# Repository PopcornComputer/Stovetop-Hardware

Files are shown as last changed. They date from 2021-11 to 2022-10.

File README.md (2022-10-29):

# Stovetop Hardware
[][cc-by-nc-sa]
[][twitter-follow]
[][sourceparts-subreddit]

## Purchase
**Stovetop™** is available for purchase in our webstore: [https://shop.popcorncomputer.com/products/stovetop][webstore]

## Documentation
To view the documentation for **Stovetop™** please visit: [https://docs.popcorncomputer.com/Stovetop][stovetop-docs]

If you have done something cool with **Stovetop™** or feel that something is missing from the documentation, please feel free to open an issue in the [documentation repository][documentation-repo] or submit a Pull Request in that repository. The source files for our documentation website can be found in the /docs folder in the [documentation repository][documentation-repo].

## License & Copyright
This work is licensed under a
[Creative Commons Attribution-NonCommercial-ShareAlike 4.0 International License][cc-by-nc-sa].

[][cc-by-nc-sa]

Source Parts Inc. © 2022

**Stovetop™** is a trademark of Source Parts Inc.

[cc-by-nc-sa]: http://creativecommons.org/licenses/by-nc-sa/4.0/
[cc-by-nc-sa-image]: https://licensebuttons.net/l/by-nc-sa/4.0/88x31.png
[cc-by-nc-sa-shield]: https://img.shields.io/badge/License-CC%20BY--NC--SA%204.0-lightgrey.svg
[twitter-follow]: https://twitter.com/intent/follow?screen_name=sourceparts
[twitter-follow-shield]: https://img.shields.io/twitter/follow/sourceparts?style=social&logo=twitter
[sourceparts-subreddit]: https://reddit.com/r/sourceparts
[reddit-subscribers-shield]: https://img.shields.io/reddit/subreddit-subscribers/sourceparts?style=social
[stovetop-docs]: https://docs.popcorncomputer.com/Stovetop
[webstore]: https://shop.popcorncomputer.com/products/stovetop
[documentation-repo]: https://github.com/PopcornComputer/Stovetop

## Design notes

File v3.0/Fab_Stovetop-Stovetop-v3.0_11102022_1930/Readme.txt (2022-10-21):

Board name	: Stovetop
Rev		: 3.0

Board Technology information:

No. of Layers		- Six(6)

Board Size 		- 72.5mm x 72.5mm

Track/Spacing		- 5mil track and 5mil spacing

Via			- 16mil pad and 8mil drill
               
Component		- Mixed Technology

Gerber Format		- RS274-X

=================================================================

Note :

Please refer fab.gbr for stackup details.

Please confirm IPC netlist verification.

=================================================================

List of files in GERBER / arttoplotting

L1_Top.gbr		-> Gerber, Top side artwork
L2_Gnd.gbr		-> Gerber, Inner layer2 artwork
L3_Sig.gbr		-> Gerber, Inner layer3 artwork
L4_Sig.gbr		-> Gerber, Inner layer4 artwork
L5_Pwr.gbr		-> Gerber, Inner layer5 artwork
L6_Bot.gbr		-> Gerber, Bot side artwork
Soldermask_Top.gbr	-> Gerber, Top side Solder Mask
Soldermask_Bot.gbr	-> Gerber, Bot side Solder Mask
Silk_Top.gbr		-> Gerber, Top side Silkscreen
Silk_Bot		-> Gerber, Bot side Silkscreen
Milling.gml		-> Gml, Milling Details
Profile.gbr		-> Gerber, Outline

List of files in DRILL/ NC Drill

Stovetop_V3.0-1-6.xln		-> NC Drill file in excellon format
Fab.gbr		   		-> Gerber, Fab drawing

Stovetop-v3.0_Release.pdf -> File for visual compliance

Stovetop-v3.0_Release.IPC -> IPC-D-356 netlist

Stovetop-v3.0_Milling.pdf -> Milling Details

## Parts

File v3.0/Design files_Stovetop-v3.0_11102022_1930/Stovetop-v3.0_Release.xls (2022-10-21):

Part | Value | Device | Package
C1 | 10NF/35V | CAP0402-CAP | 0402-CAP
C2 | 10NF/35V | CAP0402-CAP | 0402-CAP
C3 | 10NF/35V | CAP0402-CAP | 0402-CAP
C4 | 10NF/35V | CAP0402-CAP | 0402-CAP
C5 | 10uF | CAP0603-CAP | 0603-CAP
C6 | 100nF | CAPACITOR | 1608_0603
C7 | 22uF | C1206_22UF_50V_10% | C1206
C8 | 10uF | CAP0603-CAP | 0603-CAP
C9 | 22uF | CAP0805 | 805
C10 | 100nF | C0402_100NF_50V_10% | C0402
C11 | 22uF | CAP0805 | 805
C12 | 10uF | CAP0603-CAP | 0603-CAP
C13 | 22uF | CAP0805 | 805
C14 | 22uF | CAP0805 | 805
C15 | 1uF | CAP0603-CAP | 0603-CAP
C16 | 1uF | CAP0603-CAP | 0603-CAP
C17 | 100nF | CAPACITOR | 1608_0603
C18 | 100nF | CAPACITOR | 1608_0603
C19 | 100nF | CAPACITOR | 1608_0603
C20 | 100nF | CAPACITOR | 1608_0603
C21 | 100nF | CAPACITOR | 1608_0603
C22 | 100nF | CAPACITOR | 1608_0603
C23 | 10uF | CAPACITOR | 1608_0603
C24 | 100nF | CAPACITOR | 1608_0603
C25 | 100nF | CAPACITOR | 1608_0603
C26 | 18pF | CAPACITOR | 1608_0603
C27 | 18pF | CAPACITOR | 1608_0603
C28 | 10uF | CAPACITOR | 1608_0603
C29 | 100nF | CAPACITOR | 1608_0603
C30 | 100nF | CAPACITOR | 1608_0603
C31 | 10uF | CAPACITOR | 1608_0603
C32 | 100nF | CAPACITOR | 1608_0603
C33 | 10uF | CAPACITOR | 1608_0603
C34 | 100nF | CAPACITOR | 1608_0603
C35 | 100nF | CAPACITOR | 1608_0603
C36 | 10uF | CAPACITOR | 1608_0603
C37 | 100nF | CAPACITOR | 1608_0603
C38 | 10uF | CAPACITOR | 1608_0603
C39 | 4.7uF | CAPACITOR | 1608_0603
C40 | 4.7uF | CAPACITOR | 1608_0603
C41 | 100nF | CAPACITOR | 1608_0603
C42 | 10uF | CAPACITOR | 1608_0603
C43 | 220pF | CAP0603-CAP | 0603-CAP
C44 | 220pF | CAP0603-CAP | 0603-CAP
C45 | 220pF | CAP0603-CAP | 0603-CAP
C46 | 220pF | CAP0603-CAP | 0603-CAP
C47 | 47uF | CPOL-USD/7343-31W | D/7343-31W
C48 | 47uF | CPOL-USD/7343-31W | D/7343-31W
C49 | 10uF | 4.7UF-0603-6.3V-(10%) | 603
C50 | 0.1uF | CAP0402-CAP | 0402-CAP
C51 | 10uF | 4.7UF-0603-6.3V-(10%) | 603
C52 | 0.1uF | CAP0402-CAP | 0402-CAP
C53 | 0.1uF | CAP0402-CAP | 0402-CAP
C54 | 0.1uF | CAP0402-CAP | 0402-CAP
C55 | 0.01uF | CAP0402-CAP | 0402-CAP
C56 | 10uF | CAP_POL1206 | EIA3216
C57 | 22uF | CAP0805 | 805
C58 | 22uF | CAP0805 | 805
C59 | 1uF | CAP0805 | 805
C60 | 0.1uF | C-USC0402 | C0402
C61 | 10uF | C-USC0402 | C0402
C62 | 47pF | C-USC0402 | C0402
C63 | 47pF | C-USC0402 | C0402
C64 | 1uF | CAP0402-CAP | 0402-CAP
C65 | 1uF | CAP0402-CAP | 0402-CAP
C66 | 0.01uF | CAP0402-CAP | 0402-CAP
C67 | 0.01uF | CAP0402-CAP | 0402-CAP
C68 | 10uF | CAP_POL1206 | EIA3216
C69 | 0.1uF | CAP0402-CAP | 0402-CAP
C70 | 100nF | C-EUC0402 | C0402
C71 | 22nF | CAP0805 | 805
C72 | 22uF | CAP0805 | 805
C73 | 1uF | CAP0805 | 805
C74 | 0.1uF/50V | CAP0603-CAP | 0603-CAP
C75 | 10uF | CAP0603-CAP | 0603-CAP
C76 | 10uF | CAP0603-CAP | 0603-CAP
C77 | 0.1uF/50V | CAP0603-CAP | 0603-CAP
C78 | 22uF | CAP0805 | 805
C79 | 22uF | CAP0805 | 805
C80 | 22uF | CAP0805 | 805
C81 | 100nF | C-EUC0402 | C0402
C82 | 100nF | C-EUC0402 | C0402
C83 | 0.1uF | C-EUC0603 | C0603
C84 | 0.1uF | C-EUC0603 | C0603
C85 | 0.1uF | C-EUC0603 | C0603
C86 | 0.01uF | C-EUC0603 | C0603
C87 | 0.01uF | C-EUC0603 | C0603
C88 | 10uF | CPOL-EUSMCA | SMC_A
C89 | 27pf | C-EUC0603 | C0603
C90 | 27pf | C-EUC0603 | C0603
C91 | 0.1uF | C-EUC0603 | C0603
C92 | 6.8nF | C-EUC0603 | C0603
C93 | 6.8nF | C-EUC0603 | C0603
D1 | D-SEMTECH-RCLAMP0504S | D-SEMTECH-RCLAMP0504S | T_SOT95P285X90-6N
D2 | D-SEMTECH-RCLAMP0504S | D-SEMTECH-RCLAMP0504S | T_SOT95P285X90-6N
D3 | D-SEMTECH-RCLAMP0504S | D-SEMTECH-RCLAMP0504S | T_SOT95P285X90-6N
D4 | B240A | B240A | SMA
J1 | POCKETCHIP-V1.0_98401-801-40LF | POCKETCHIP-V1.0_98401-801-40LF | POCKETCHIP-V1.0_98401-801-40LF
J2 | HR911105A | HR911105A | HR911105A
J3 | STOVETOP-V2.0_03062020_1600_STOVETOP-V2.0_CHECK_TRISTAN-ROBITAILLE'S-LIBRARY_DX07S024JJ2_USB_TYPE-C | STOVETOP-V2.0_03062020_1600_STOVETOP-V2.0_CHECK_TRISTAN-ROBITAILLE'S-LIBRARY_DX07S024JJ2_USB_TYPE-C | STOVETOP-V2.0_03062020_1600_STOVETOP-V2.0_CHECK_TRISTAN-ROBITAILLE'S-LIBRARY_DX07S0224JJ2_USB-C
J4 | STOVETOP-V2.0_03062020_1600_STOVETOP-V2.0_CHECK_TRISTAN-ROBITAILLE'S-LIBRARY_DX07S024JJ2_USB_TYPE-C | STOVETOP-V2.0_03062020_1600_STOVETOP-V2.0_CHECK_TRISTAN-ROBITAILLE'S-LIBRARY_DX07S024JJ2_USB_TYPE-C | STOVETOP-V2.0_03062020_1600_STOVETOP-V2.0_CHECK_TRISTAN-ROBITAILLE'S-LIBRARY_DX07S0224JJ2_USB-C
J5 |  | CONN_02LOCK | 1X02_LOCK
J6 |  | CONN_02LOCK | 1X02_LOCK
J8 | HDMI_T_MOLEX_45171 | CHIP_HDMI_T_MOLEX_45171 | CHIP_HDMI_T_MOLEX_45171
JP1 | JUMPER-SMT_3_1-NC_PASTE_SILK | JUMPER-SMT_3_1-NC_PASTE_SILK | SMT-JUMPER_3_1-NC_PASTE_SILK
JP2 | JUMPER-SMT_3_1-NC_PASTE_SILK | JUMPER-SMT_3_1-NC_PASTE_SILK | SMT-JUMPER_3_1-NC_PASTE_SILK
JP4 | JUMPER-PAD-2-NC_BY_TRACE | JUMPER-PAD-2-NC_BY_TRACE | PAD-JUMPER-2-NC_BY_TRACE_YES_SILK
JP5 | JUMPER-PAD-2-NC_BY_TRACE | JUMPER-PAD-2-NC_BY_TRACE | PAD-JUMPER-2-NC_BY_TRACE_YES_SILK
L1 | IND_4.7UH | IND_4.7UH | IND_4.7UH
L2 | ACML | ACML | 603
L3 | ACML | ACML | 603
L4 | ACML | ACML | 603
L5 | ACML | ACML | 603
L6 | ACML | ACML | 603
L7 |  | WE-KIL_0805 | WE-KI_0805_B
Q5 | FTX25.000M12SM3S | CRISTALLI_0846_FTX25.000M12SM3S | CRISTALLI_CRYSTAL3.2X2.5
R1 | 49R9 1% | R-EU_R0603 | R0603
R2 | 49R9 1% | R-EU_R0603 | R0603
R3 | 49R9 1% | R-EU_R0603 | R0603
R4 | 19.1K | R-US_R0402 | R0402
R5 | 10K | R-US_R0402 | R0402
R6 | 49R9 1% | R-EU_R0603 | R0603
R7 | 28K | R-US_R0402 | R0402
R8 | 1.2K | RESISTOR | J1-0603
R9 | 6.7K | RESISTOR | J1-0603
R10 | 10K | R-US_R0402 | R0402
R11 | 10K | R-US_R0402 | R0402
R12 | 4.7K | R0402_4K7_5% | R0402
R13 | 10K | R-US_R0402 | R0402
R14 | 6.7K | RESISTOR | J1-0603
R15 | 1M | RESISTOR | J1-0603
R16 | 10k | RESISTOR | J1-0603
R17 | 10k | RESISTOR | J1-0603
R18 | 10k | RESISTOR | J1-0603
R19 | 10k | RESISTOR | J1-0603
R20 | 10k | RESISTOR | J1-0603
R21 | 10k | RESISTOR | J1-0603
R22 | 47k | RESISTOR | J1-0603
R23 | 1M | R-US_R0402 | R0402
R24 | 10K | R-US_R0402 | R0402
R25 | 330K | R-US_R0402 | R0402
R26 | 20K | R-US_R0603 | R0603
R27 | 1K1 | R-EU_R0603 | R0603
R28 | 100K | R-US_R0402 | R0402
R29 | 100K | R-US_R0402 | R0402
R30 | 10K | R-US_R0402 | R0402
R31 | 10K | R-US_R0402 | R0402
R32 | 10K | R-US_R0402 | R0402
R33 | 10K | R-US_R0402 | R0402
R34 | 10K | R-US_R0402 | R0402
R35 | 1K1 | R-EU_R0603 | R0603
R36 | 100K | RESISTOR | J1-0603
R37 | 12.4K 1% | R-EU_R0603 | R0603
R38 | 100K | RESISTOR | J1-0603
R39 | 1K | R-US_R0402 | R0402
R40 | 1K | R-US_R0402 | R0402
R41 | 10R, 1/12W, 1% | R-EU_R0603 | R0603
R42 | 100K | R-EU_R0603 | R0603
R44 | 22R | R-EU_R0603 | R0603
R45 | 0 | R-US_R0402 | R0402
R46 | 27R | R-US_R0402 | R0402
R47 | 27R | R-US_R0402 | R0402
R48 | 100K | RESISTOR | J1-0603
R49 | 100K | RESISTOR | J1-0603
R50 | 100R | RESISTOR | J1-0603
R51 | 100R | RESISTOR | J1-0603
R52 | 100K | RESISTOR | J1-0603
RX_LED | Blue | LED805 | LED-805
S1 | 1TS009A | 1TS009A | 1TS009A
S2 | 1TS009A | 1TS009A | 1TS009A
SJ3 | SPARKFUN_SOLDERJUMPERTRACE | SPARKFUN_SOLDERJUMPERTRACE | SPARKFUN_SJ_2S-TRACE
TP1 | CHIP_HDMI_TEST_POINT | CHIP_HDMI_TEST_POINT | CHIP_HDMI_TP-1MMX1MM
TP2 | TEST_POINT | TEST_POINT | TP-1MMX1MM
TP4 | TEST_POINT | TEST_POINT | TP-1MMX1MM
TP5 | TEST_POINT | TEST_POINT | TP-1MMX1MM
TP6 | TEST_POINT | TEST_POINT | TP-1MMX1MM
TP7 | TEST_POINT | TEST_POINT | TP-1MMX1MM
TP8 | TEST_POINT | TEST_POINT | TP-1MMX1MM
TP9 | TEST_POINT | TEST_POINT | TP-1MMX1MM
TP10 | TEST_POINT | TEST_POINT | TP-1MMX1MM
TP11 | TEST_POINT | TEST_POINT | TP-1MMX1MM
TP12 | TEST_POINT | TEST_POINT | TP-1MMX1MM
TP13 | TEST_POINT | TEST_POINT | TP-1MMX1MM
TVS1 | TVS2200 | TVS2200 | TVS2200
TVS2 | TVS2200 | TVS2200 | TVS2200
TX_LED | Amber | LED805 | LED-805
U1 | TPD6S300 | TPD6S300 | TPD6S300
U2 | TPD6S300 | TPD6S300 | TPD6S300
U3 | DS2431P | DS2431P | TSOC6
U4 | CH7053A | CH7053A | QFN40P1000X1000X90_HS-89M
U5 | LP5907MFX | LP5907MFX | SOT23-5
U6 | MP28167GQ | MP28167GQ | MP28167GQ
U7 | PCM1803SMD | PCM1803SMD | SSOP20
U8 | TPS65988 | TPS65988 | TPS65988
U9 | W25X05CLSNIG | W25X05CLSNIG | W25X05CLSNIG
U10 | ENC424J600 | ENC424J600 | TQFP44
UN0 | FT230XS | FT230XS | SSOP-16
Y1 | ABM3B | ABM3B | ABM3B
Y2 | 24.576MHz OSCILLATOR | OSCILLATORSMD6 | CRYSTAL-SMD-7.5X5.2-6PIN

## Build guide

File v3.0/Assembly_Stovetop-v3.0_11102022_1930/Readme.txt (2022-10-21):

Board name	: Stovetop
Rev		: 3.0

Board Technology information:

No. of Layers		- Six(6)

Board Size 		- 72.5mm x 72.5mm

Track/Spacing		- 5mil track and 5mil spacing

Via			- 16mil pad and 8mil drill
               
Component		- Mixed Technology

Gerber Format		- RS274-X

=================================================================

List of files in ASSY/ for Assembly

Paste_Top.gbr		  -> Gerber, Top Side Solder Paste
Paste_Bot.gbr		  -> Gerber, Bot Side Solder Paste
Stovetop-v3.0_Release-smd -> smd component xy location
Stovetop-v3.0_Release-tht -> tht component xy location

Stovetop-v3.0_Assembly.pdf -> File for visual compliance

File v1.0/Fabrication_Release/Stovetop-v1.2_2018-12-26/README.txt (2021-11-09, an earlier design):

Board name	: Stovetop-v1	
Rev		: v0.9

Board Technology information:

No. of Layers		- FOUR(4)

Board Size 		 - 72.5mm x 64mm
               
Component		- Mixed Technology

Gerber Format		- RS274-X

Soldermask Color: WHITE
Silkscreen Color: BLACK

PCB Thickness: 1.6mm
PCB Finish: ENIG
Copper Thickness: 1oz

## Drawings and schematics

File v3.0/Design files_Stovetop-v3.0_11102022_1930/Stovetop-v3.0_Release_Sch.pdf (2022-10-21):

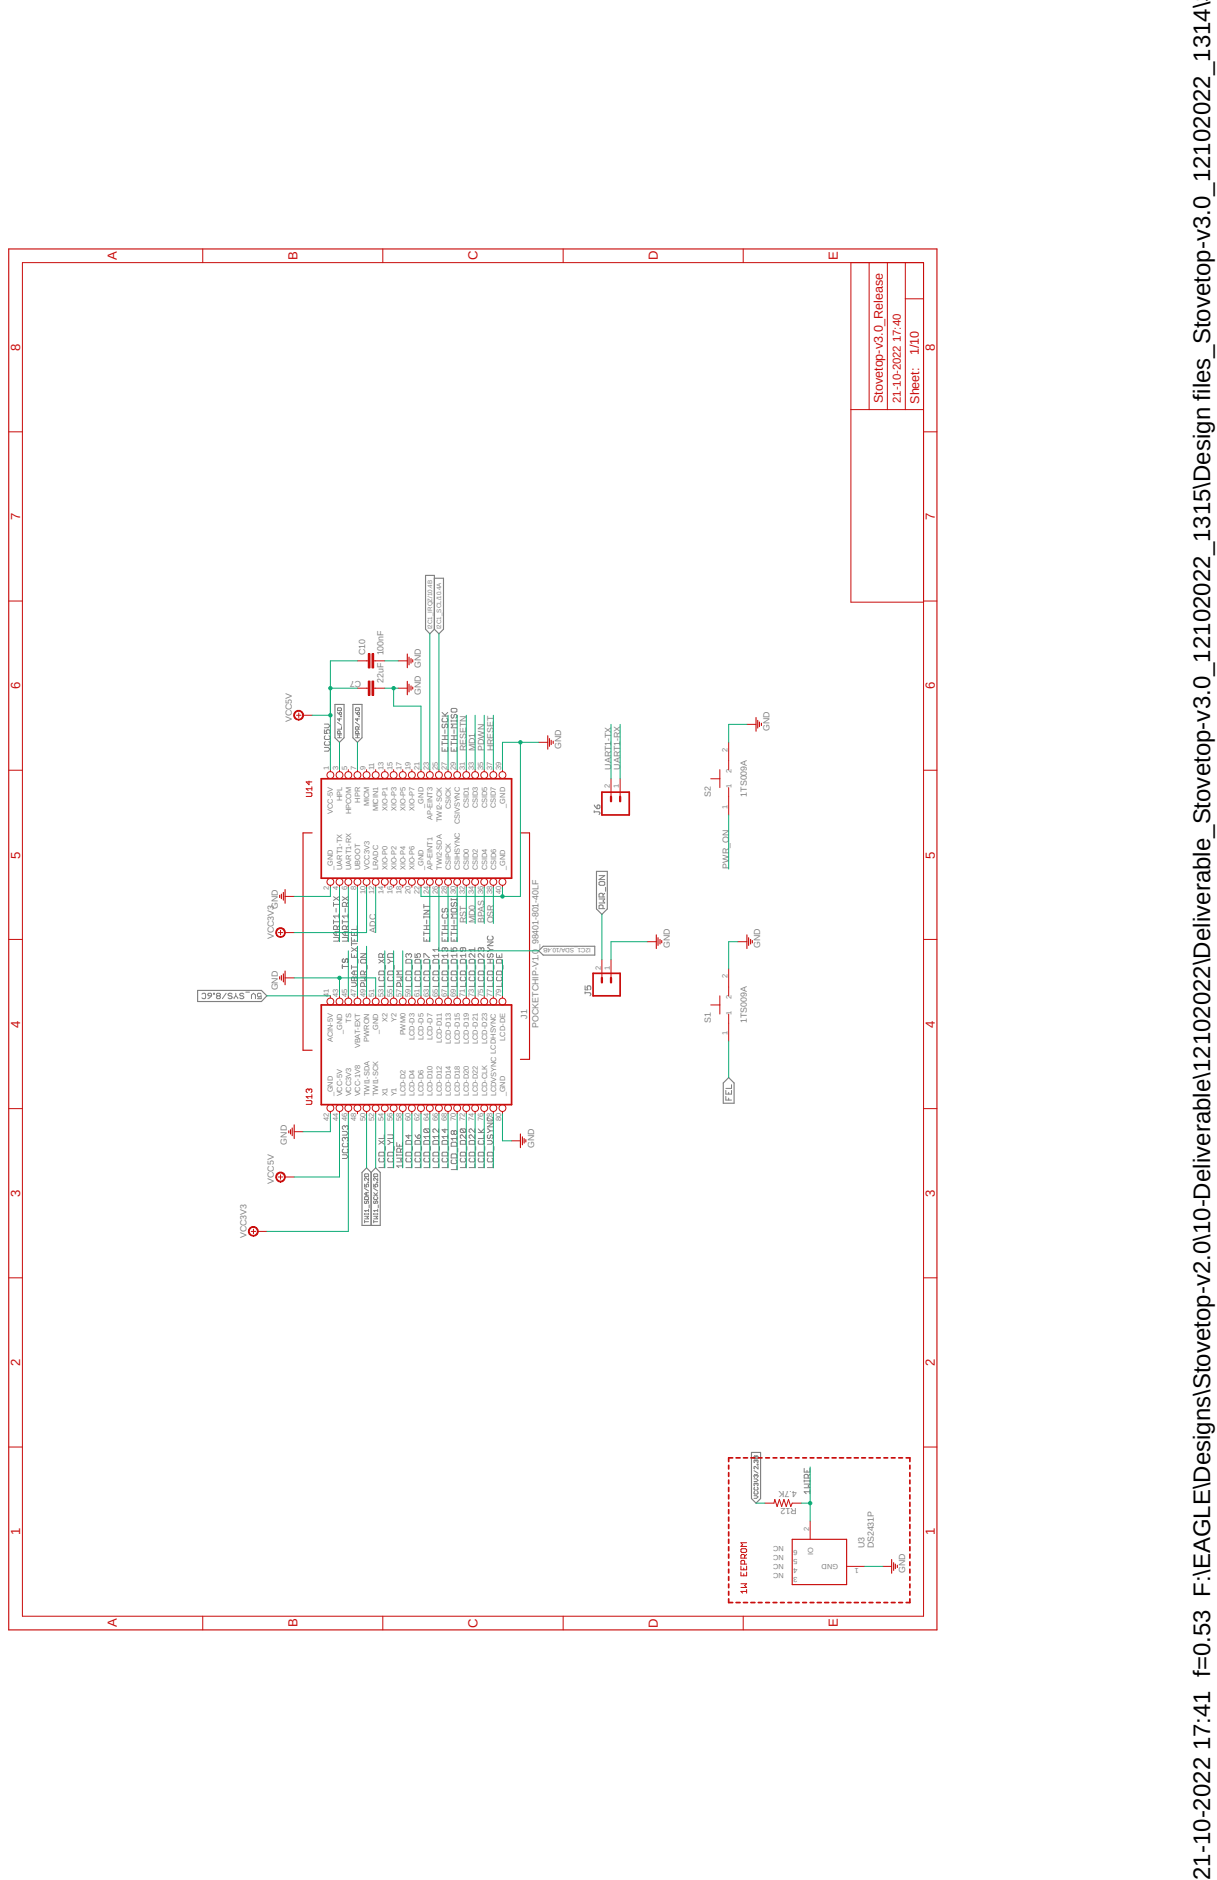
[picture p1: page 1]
GND; GND GND; VCC5V; VCC3V3; POCKETCHIP-V1.0_98401-801-40LF; ACIN-5V 41; AP-EINT1 24 AP-EINT3 23; CSICK 27; CSID0 32 CSID1 31 CSID2 34 CSID3 33 CSID4 36 CSID5 35 CSID6 38 CSID7 37; HPCOM 5; HPL 3; HPR 7; LCD-CLK 76; LCD-D2 58; LCD-D3 59 LCD-D4 60; LCD-D5 61 LCD-D6 62; LCD-D7 63 LCD-D10 64; LCD-D11 65 LCD-D12 66 LCD-D13 67 LCD-D14 68; LCD-D15 69 LCD-D18 70; LCD-D19 71 LCD-D20 72; LCD-D21 73 LCD-D22 74; LCD-D23 75; LRADC 12 MICIN1 11 MICM 9; PWM0 57; PWRON 49; TWI1-SCK 52 TWI1-SDA 50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

21-10-2022 17:41 f=0.53 F:\EAGLE\Designs\Stovetop-v2.0\10-Deliverable\12102022\Deliverable_Stovetop-v3.0_12102022_1315\Design files_Stovetop-v3.0_12102022_1314\Stovetop-v3.0_Release.sch (Sheet: 1/10)

CSIHSYNC 30 CSIPCK 28 CSIVSYNC 29

UBOOT 8 VBAT-EXT 47 VCC-1V8 48

LCD-DE 79 LCDHSYNC 77 LCDVSYNC 78

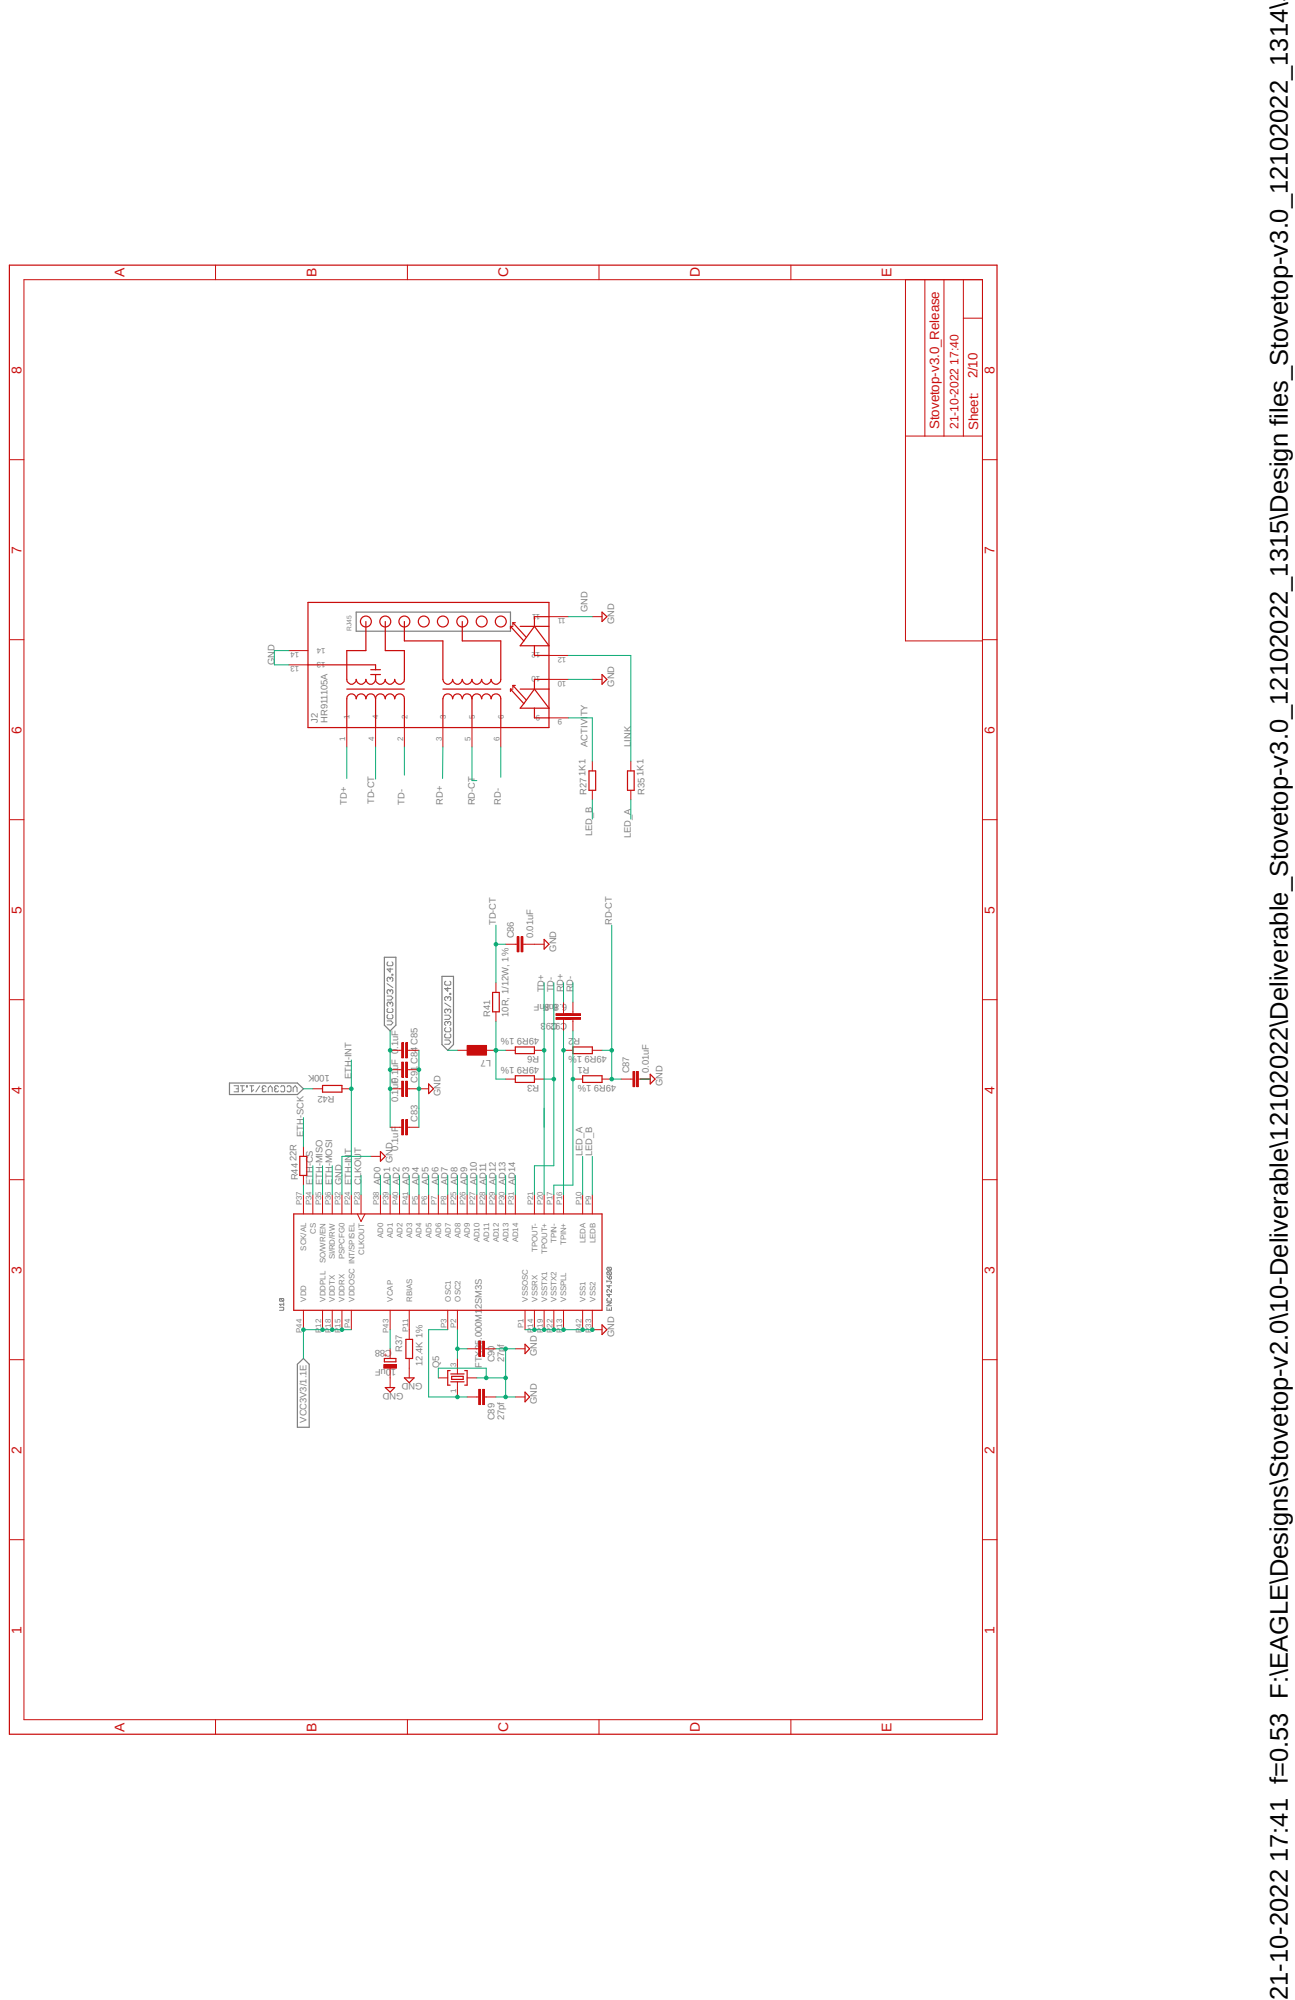
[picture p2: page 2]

21-10-2022 17:41 f=0.53 F:\EAGLE\Designs\Stovetop-v2.0\10-Deliverable\12102022\Deliverable_Stovetop-v3.0_12102022_1315\Design files_Stovetop-v3.0_12102022_1314\Stovetop-v3.0_Release.sch (Sheet: 2/10)

ETH-INT

21-10-2022 17:41 f=0.53 F:\EAGLE\Designs\Stovetop-v2.0\10-Deliverable\12102022\Deliverable_Stovetop-v3.0_12102022_1315\Design files_Stovetop-v3.0_12102022_1314\Stovetop-v3.0_Release.sch (Sheet: 3/10)

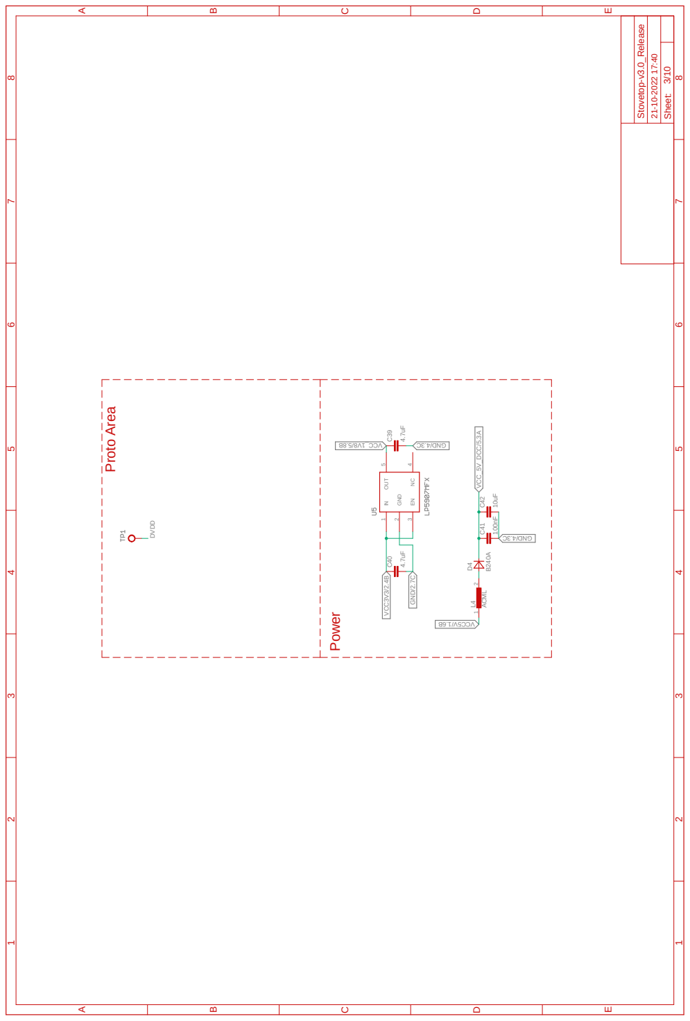
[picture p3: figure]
ACML; GND 2; OUT 5; GND/2.7C; VCC_5V_DCC/5.3A; DVDD; VCC3V3/2.4B; Proto Area; Power; Sheet:; Stovetop-v3.0_Release
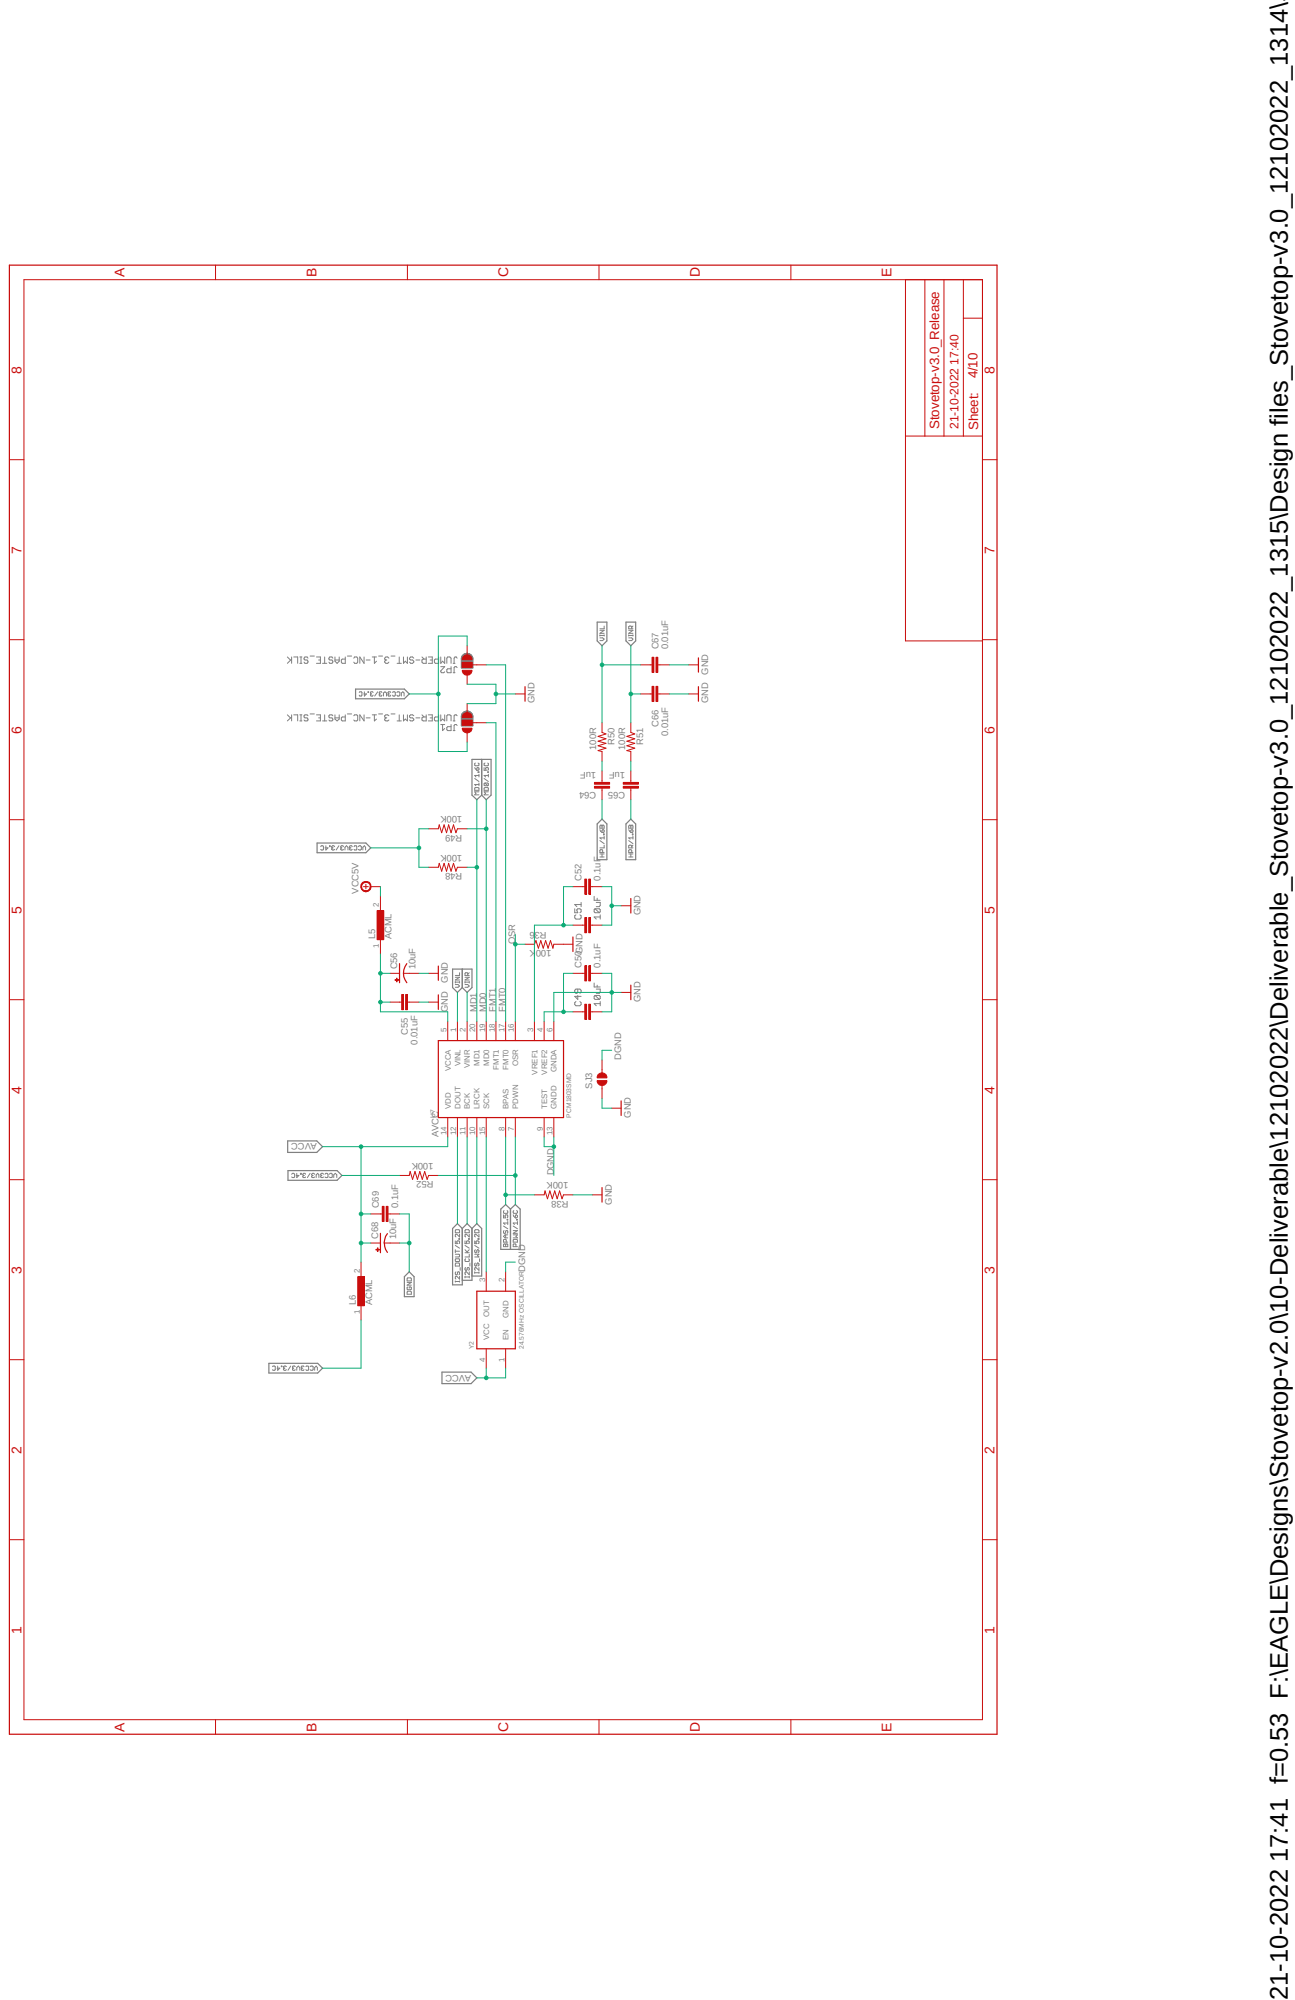
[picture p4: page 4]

21-10-2022 17:41 f=0.53 F:\EAGLE\Designs\Stovetop-v2.0\10-Deliverable\12102022\Deliverable_Stovetop-v3.0_12102022_1315\Design files_Stovetop-v3.0_12102022_1314\Stovetop-v3.0_Release.sch (Sheet: 4/10)

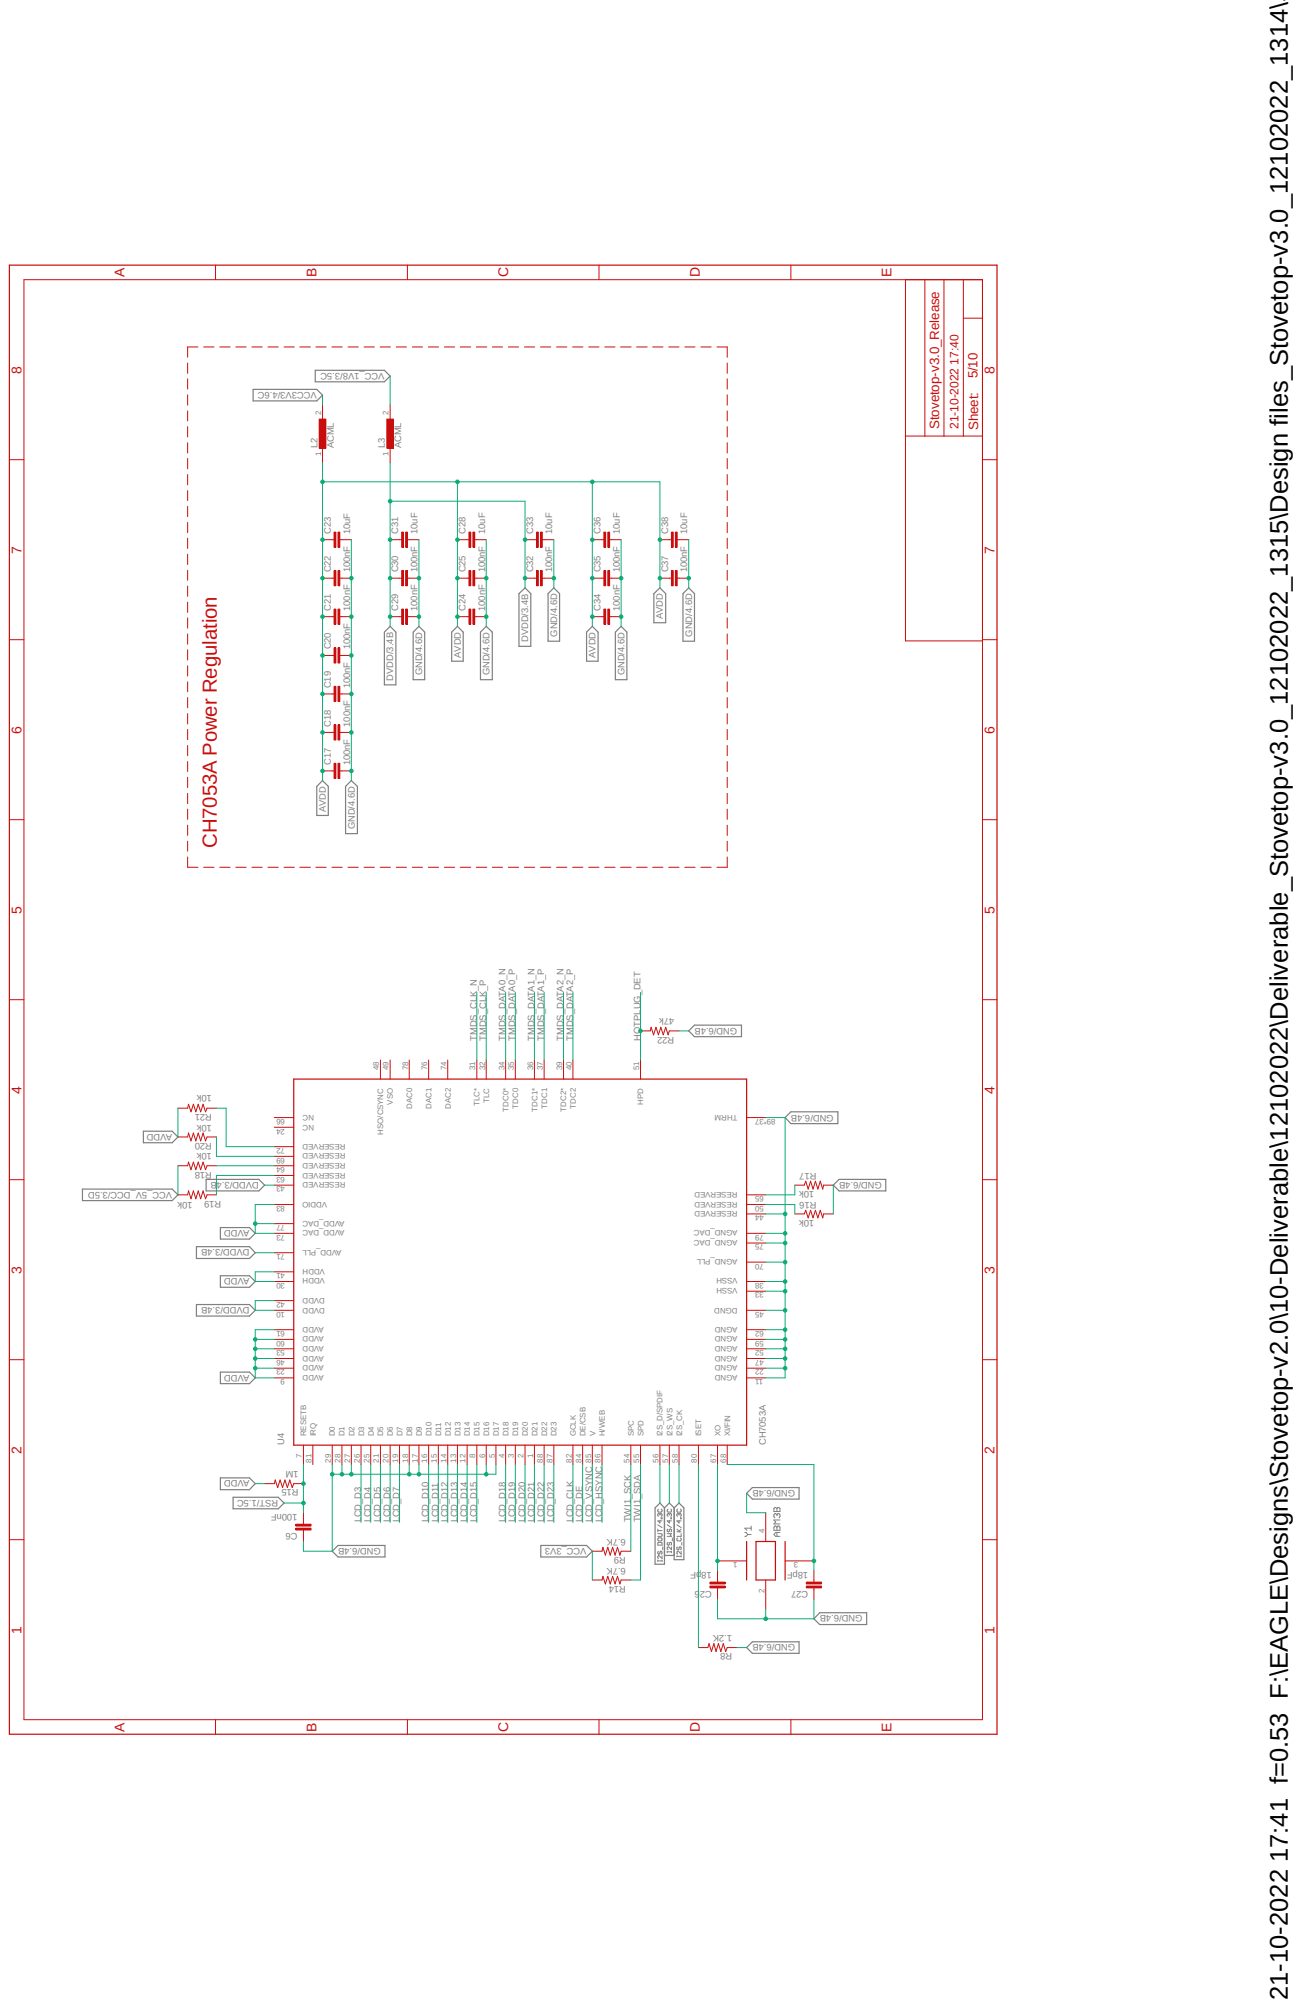
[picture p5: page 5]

21-10-2022 17:41 f=0.53 F:\EAGLE\Designs\Stovetop-v2.0\10-Deliverable\12102022\Deliverable_Stovetop-v3.0_12102022_1315\Design files_Stovetop-v3.0_12102022_1314\Stovetop-v3.0_Release.sch (Sheet: 5/10)

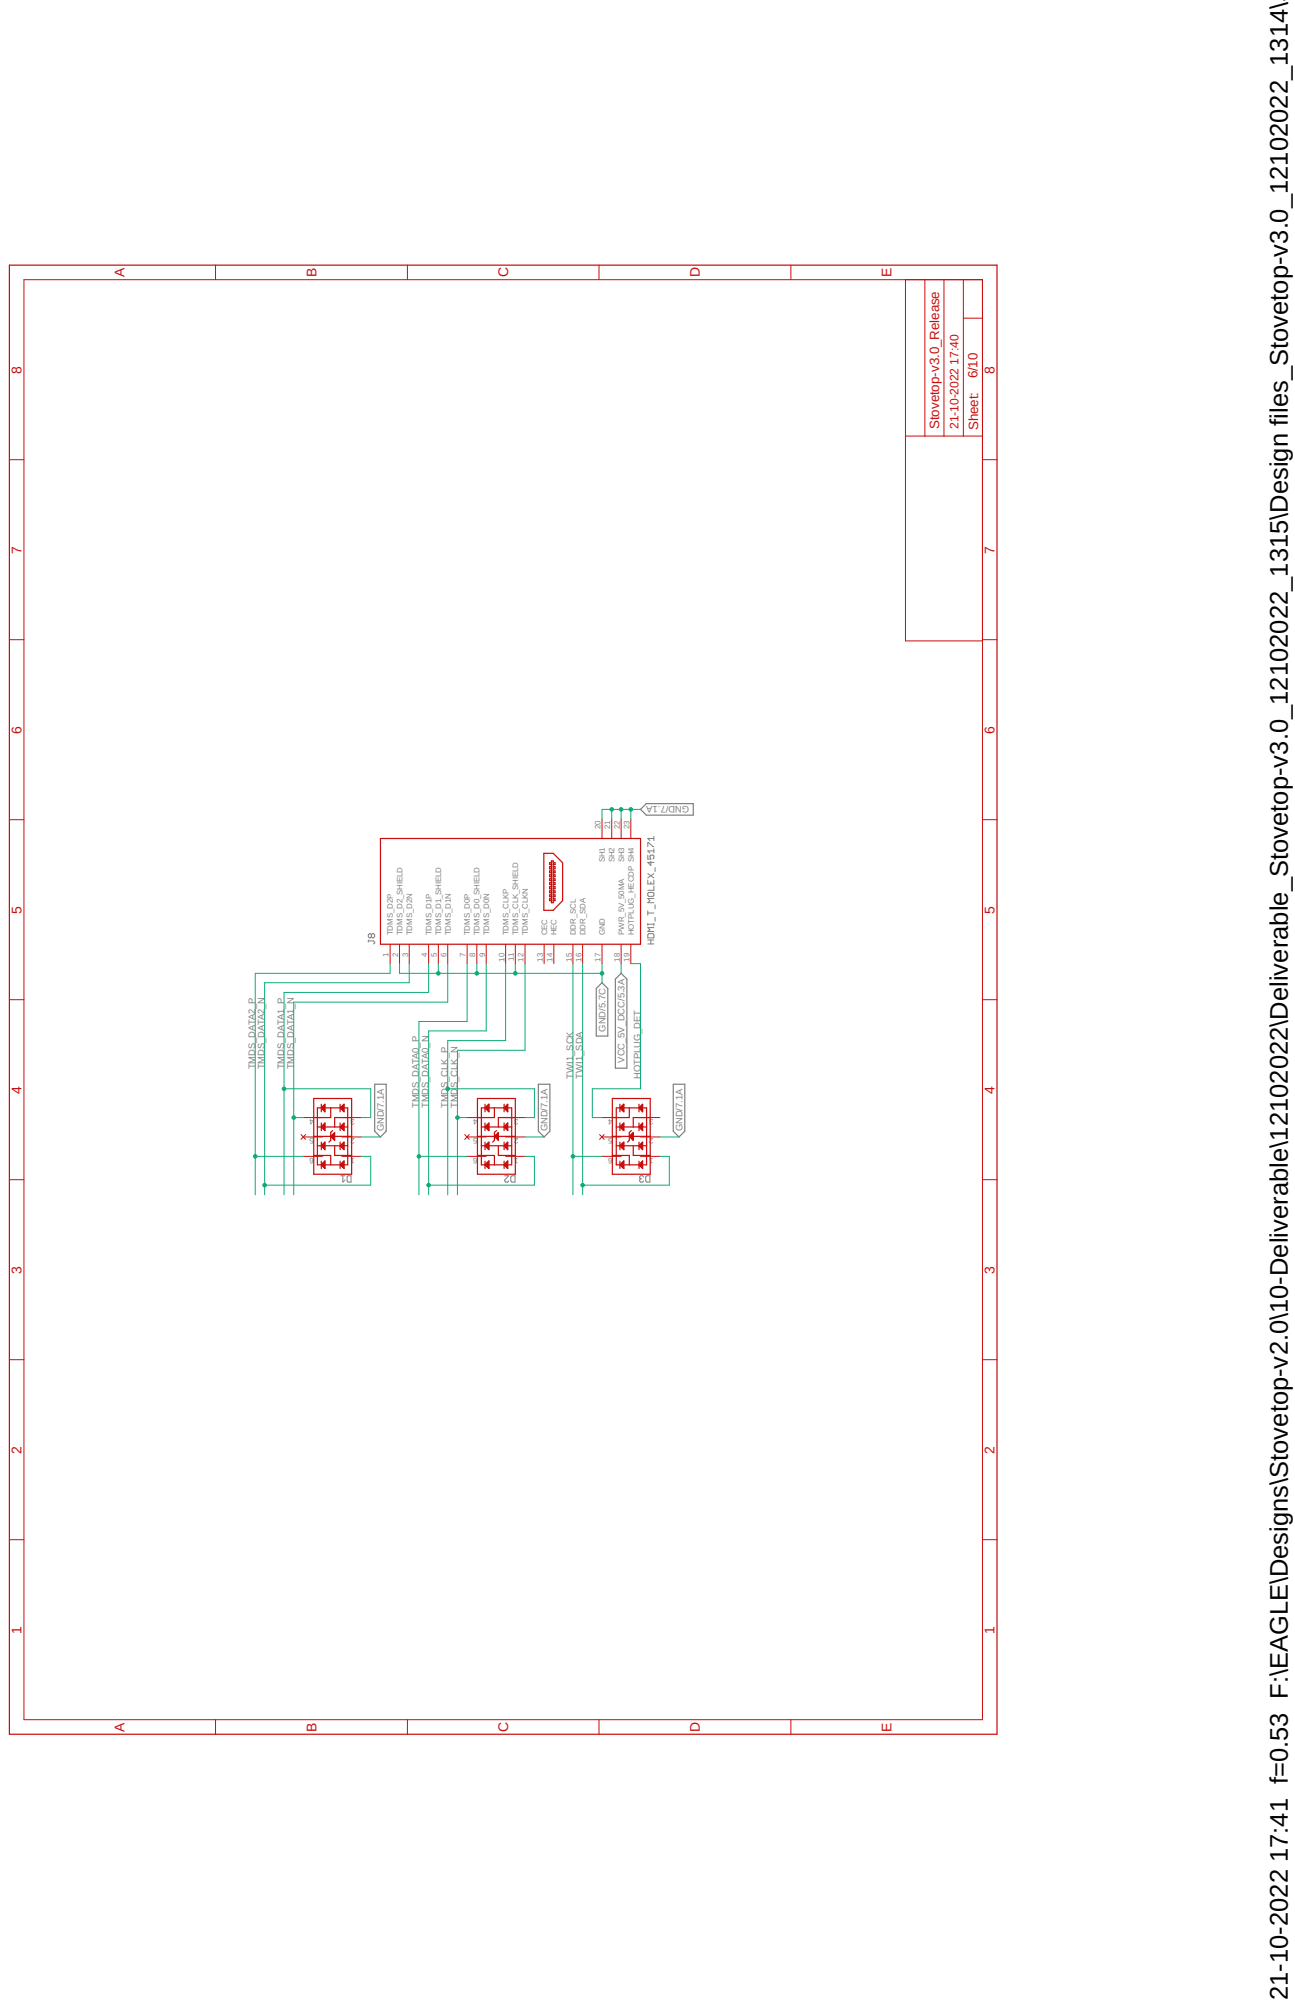
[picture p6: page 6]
CEC 13; DDR_SCL 15; DDR_SDA 16; GND 17; HEC 14; HOTPLUG_HECDP 19 PWR_5V_50MA 18; TDMS_CLKN 12; TDMS_CLKP 10; TDMS_CLK_SHIELD 11; TDMS_D0N 9; TDMS_D0P 7; TDMS_D0_SHIELD 8; TDMS_D1N 6; TDMS_D1P 4; TDMS_D1_SHIELD 5; TDMS_D2N 3; TDMS_D2P 1; TDMS_D2_SHIELD 2; GND/7.1A; GND/5.7C; TMDS_DATA2_P; TMDS_DATA2_N; TMDS_DATA1_P; TMDS_DATA1_N; TMDS_DATA0_P; TMDS_DATA0_N; TMDS_CLK_P; TMDS_CLK_N; TWI1_SCK; TWI1_SDA; HOTPLUG_DET; VCC_5V_DCC/5.3A; Sheet:; Stovetop-v3.0_Release

21-10-2022 17:41 f=0.53 F:\EAGLE\Designs\Stovetop-v2.0\10-Deliverable\12102022\Deliverable_Stovetop-v3.0_12102022_1315\Design files_Stovetop-v3.0_12102022_1314\Stovetop-v3.0_Release.sch (Sheet: 6/10)

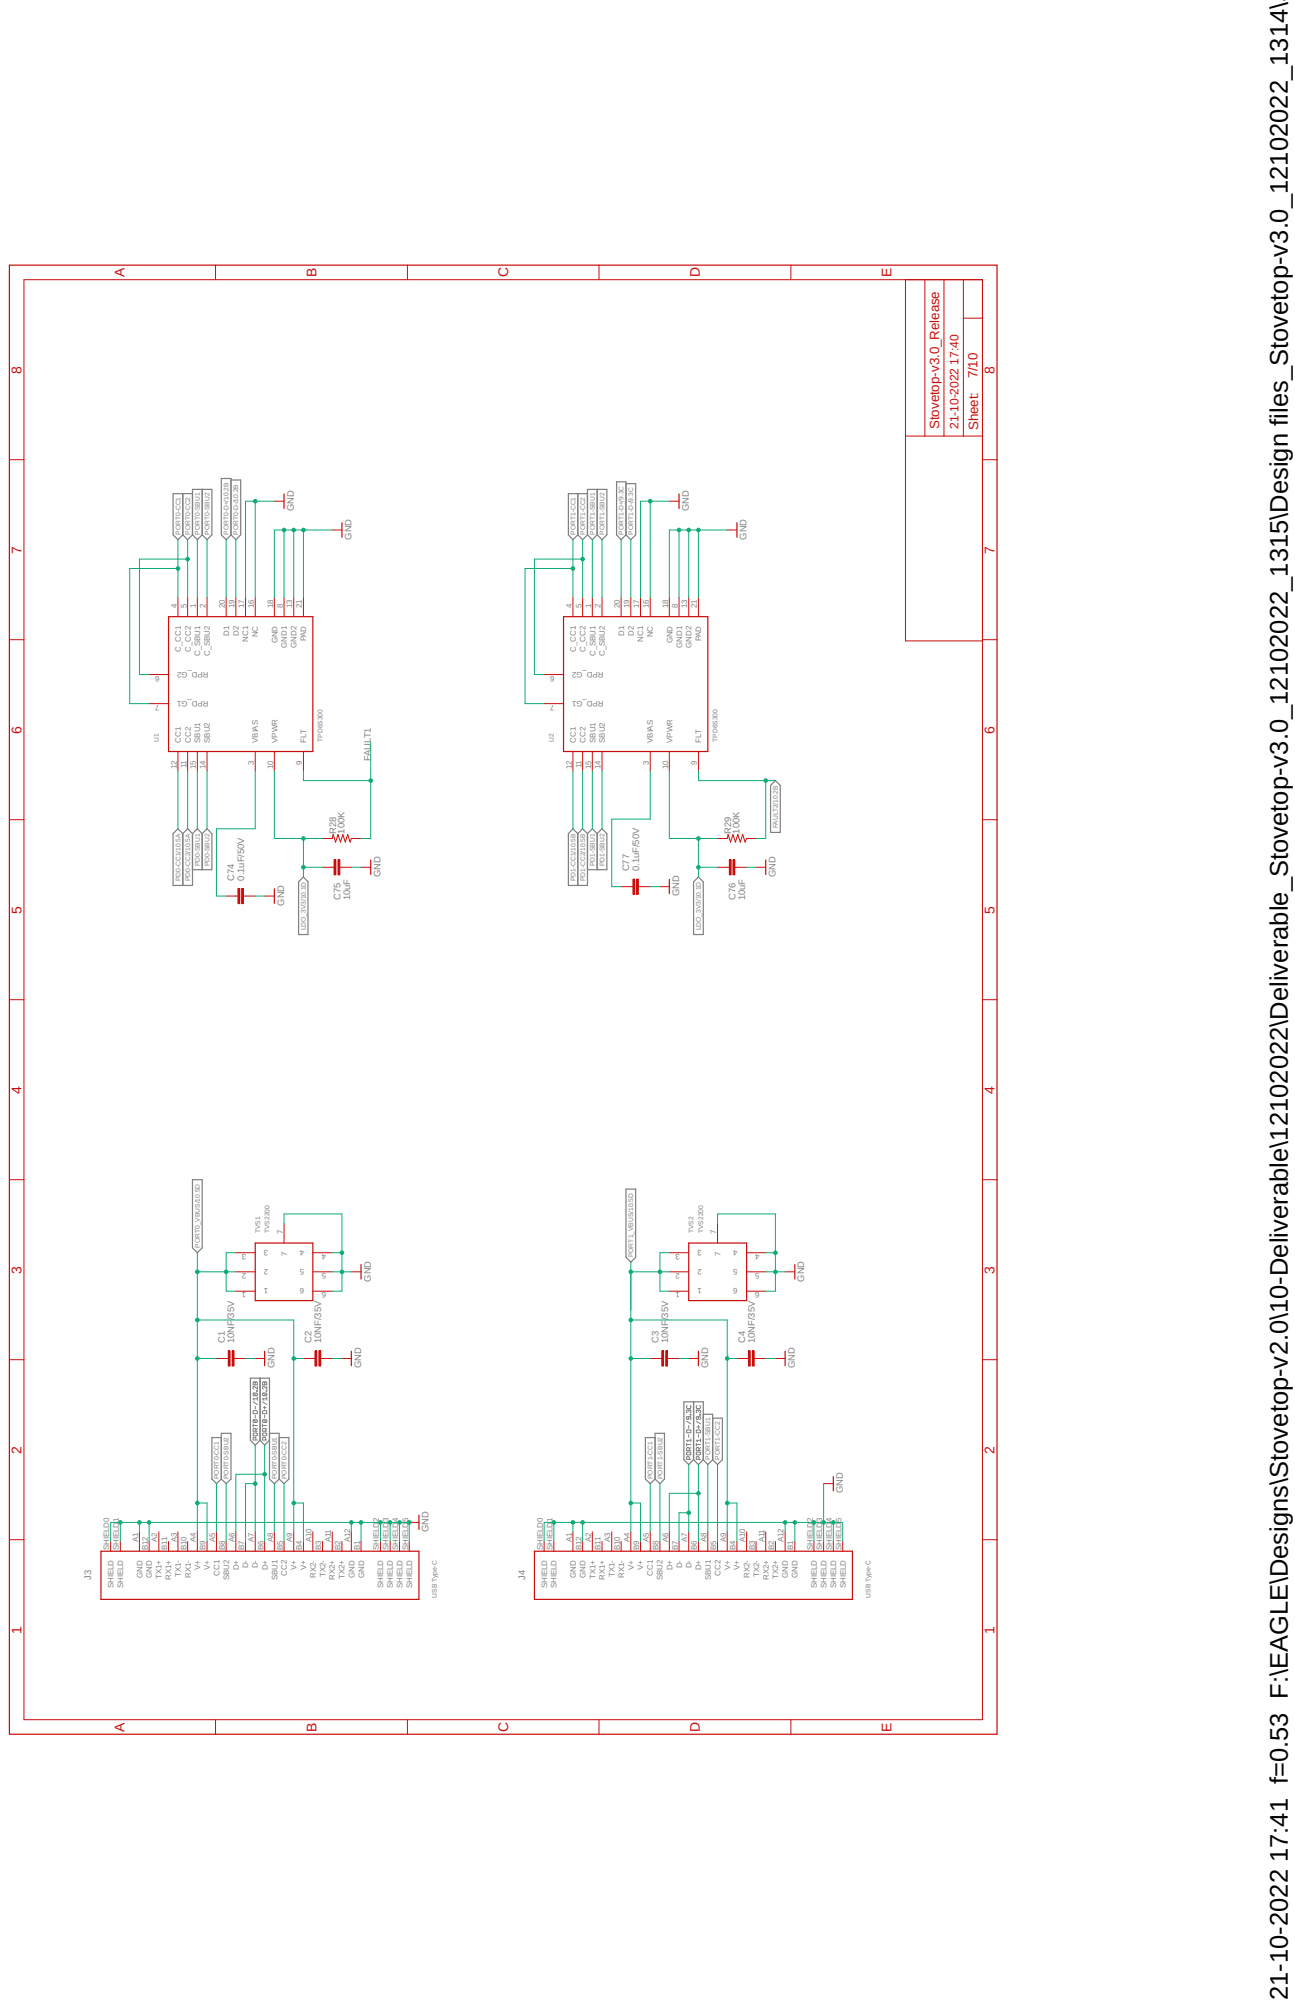
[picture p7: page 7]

21-10-2022 17:41 f=0.53 F:\EAGLE\Designs\Stovetop-v2.0\10-Deliverable\12102022\Deliverable_Stovetop-v3.0_12102022_1315\Design files_Stovetop-v3.0_12102022_1314\Stovetop-v3.0_Release.sch (Sheet: 7/10)

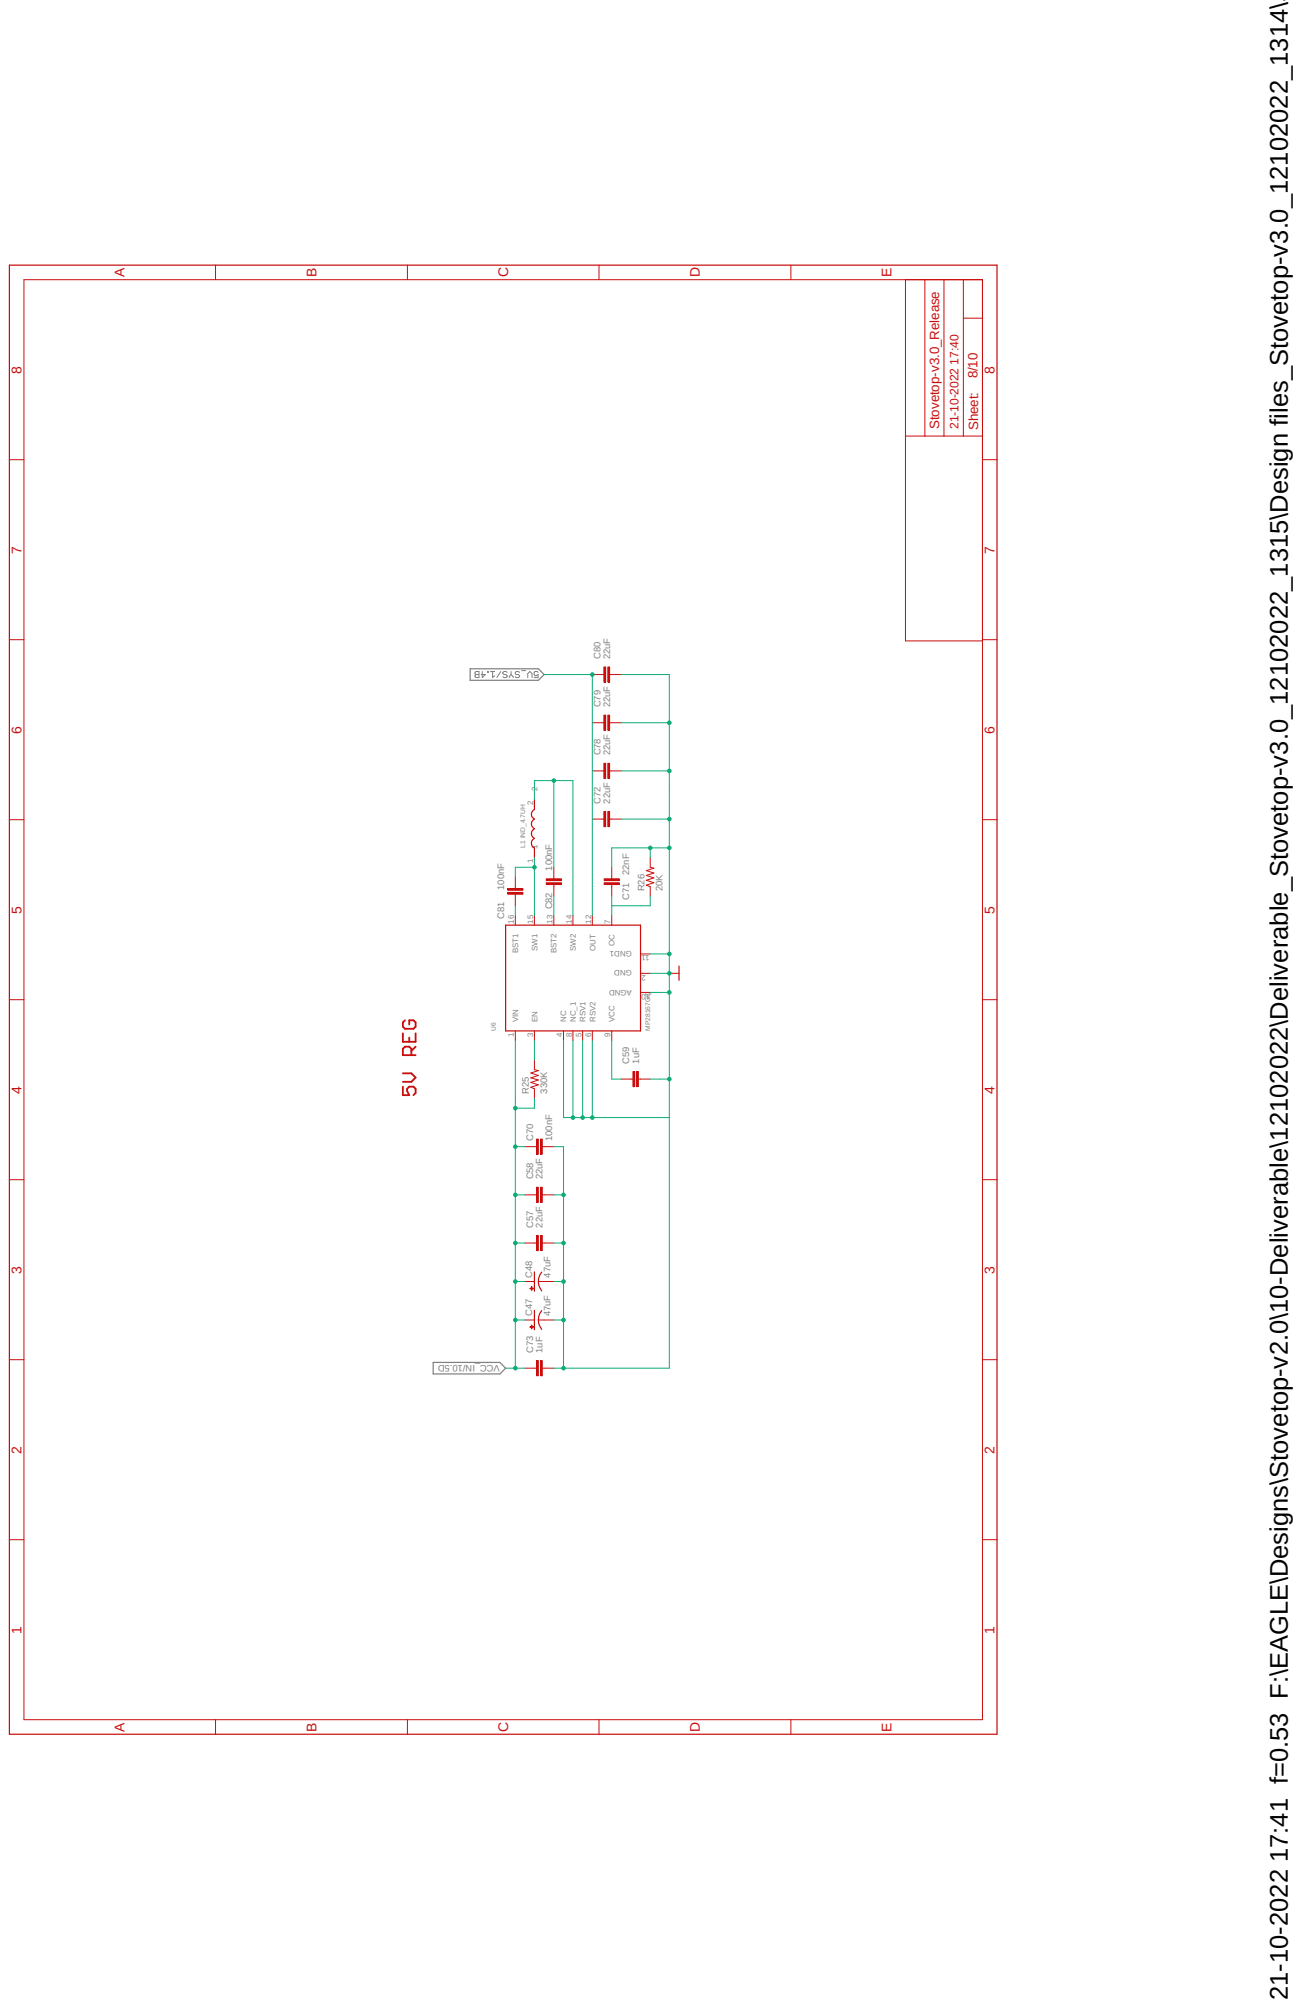
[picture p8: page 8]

21-10-2022 17:41 f=0.53 F:\EAGLE\Designs\Stovetop-v2.0\10-Deliverable\12102022\Deliverable_Stovetop-v3.0_12102022_1315\Design files_Stovetop-v3.0_12102022_1314\Stovetop-v3.0_Release.sch (Sheet: 8/10)

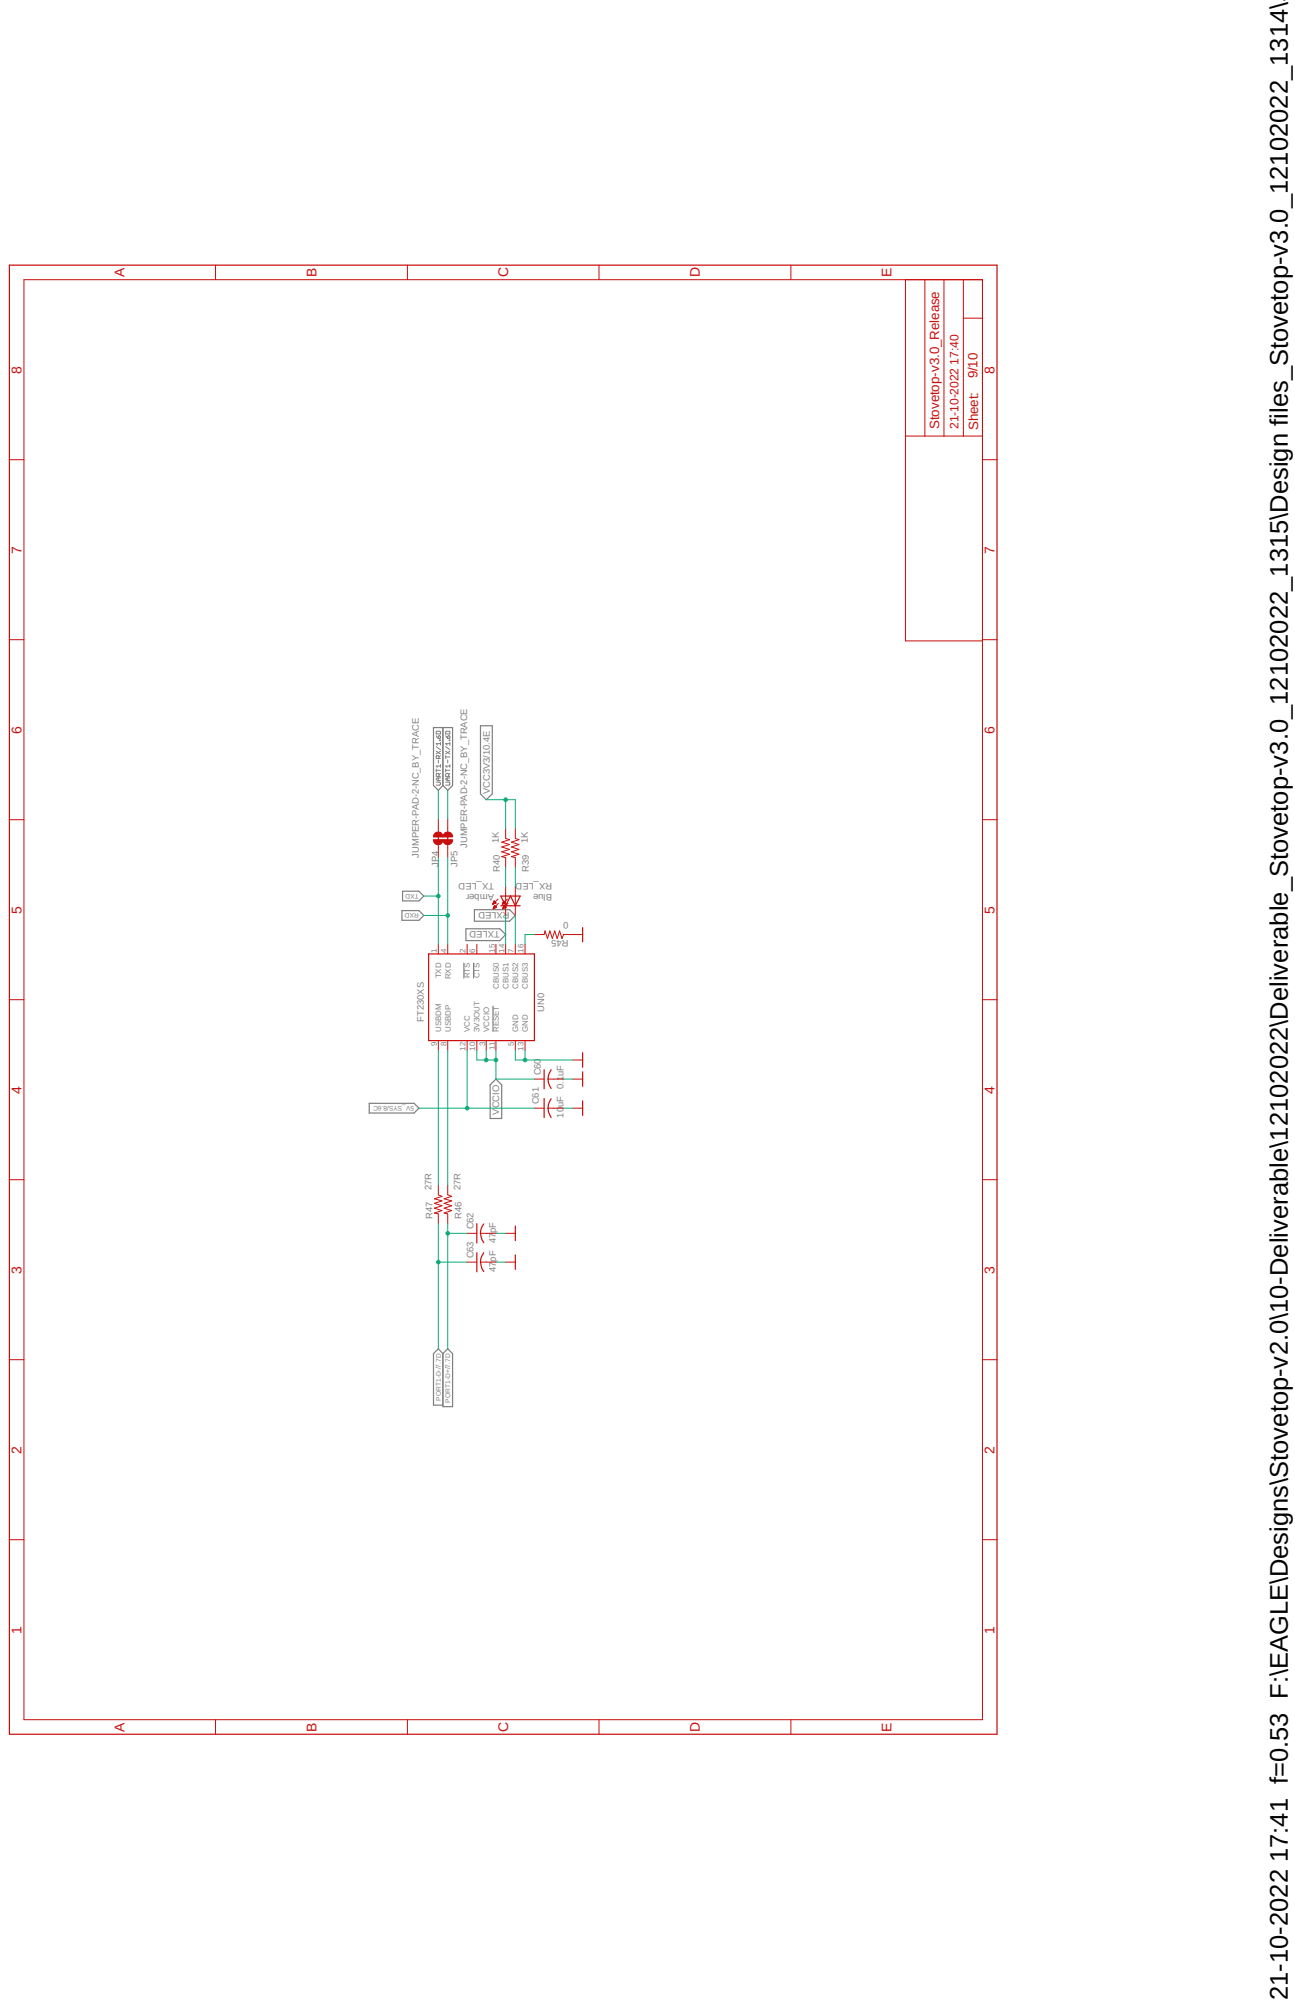
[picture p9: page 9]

21-10-2022 17:41 f=0.53 F:\EAGLE\Designs\Stovetop-v2.0\10-Deliverable\12102022\Deliverable_Stovetop-v3.0_12102022_1315\Design files_Stovetop-v3.0_12102022_1314\Stovetop-v3.0_Release.sch (Sheet: 9/10)

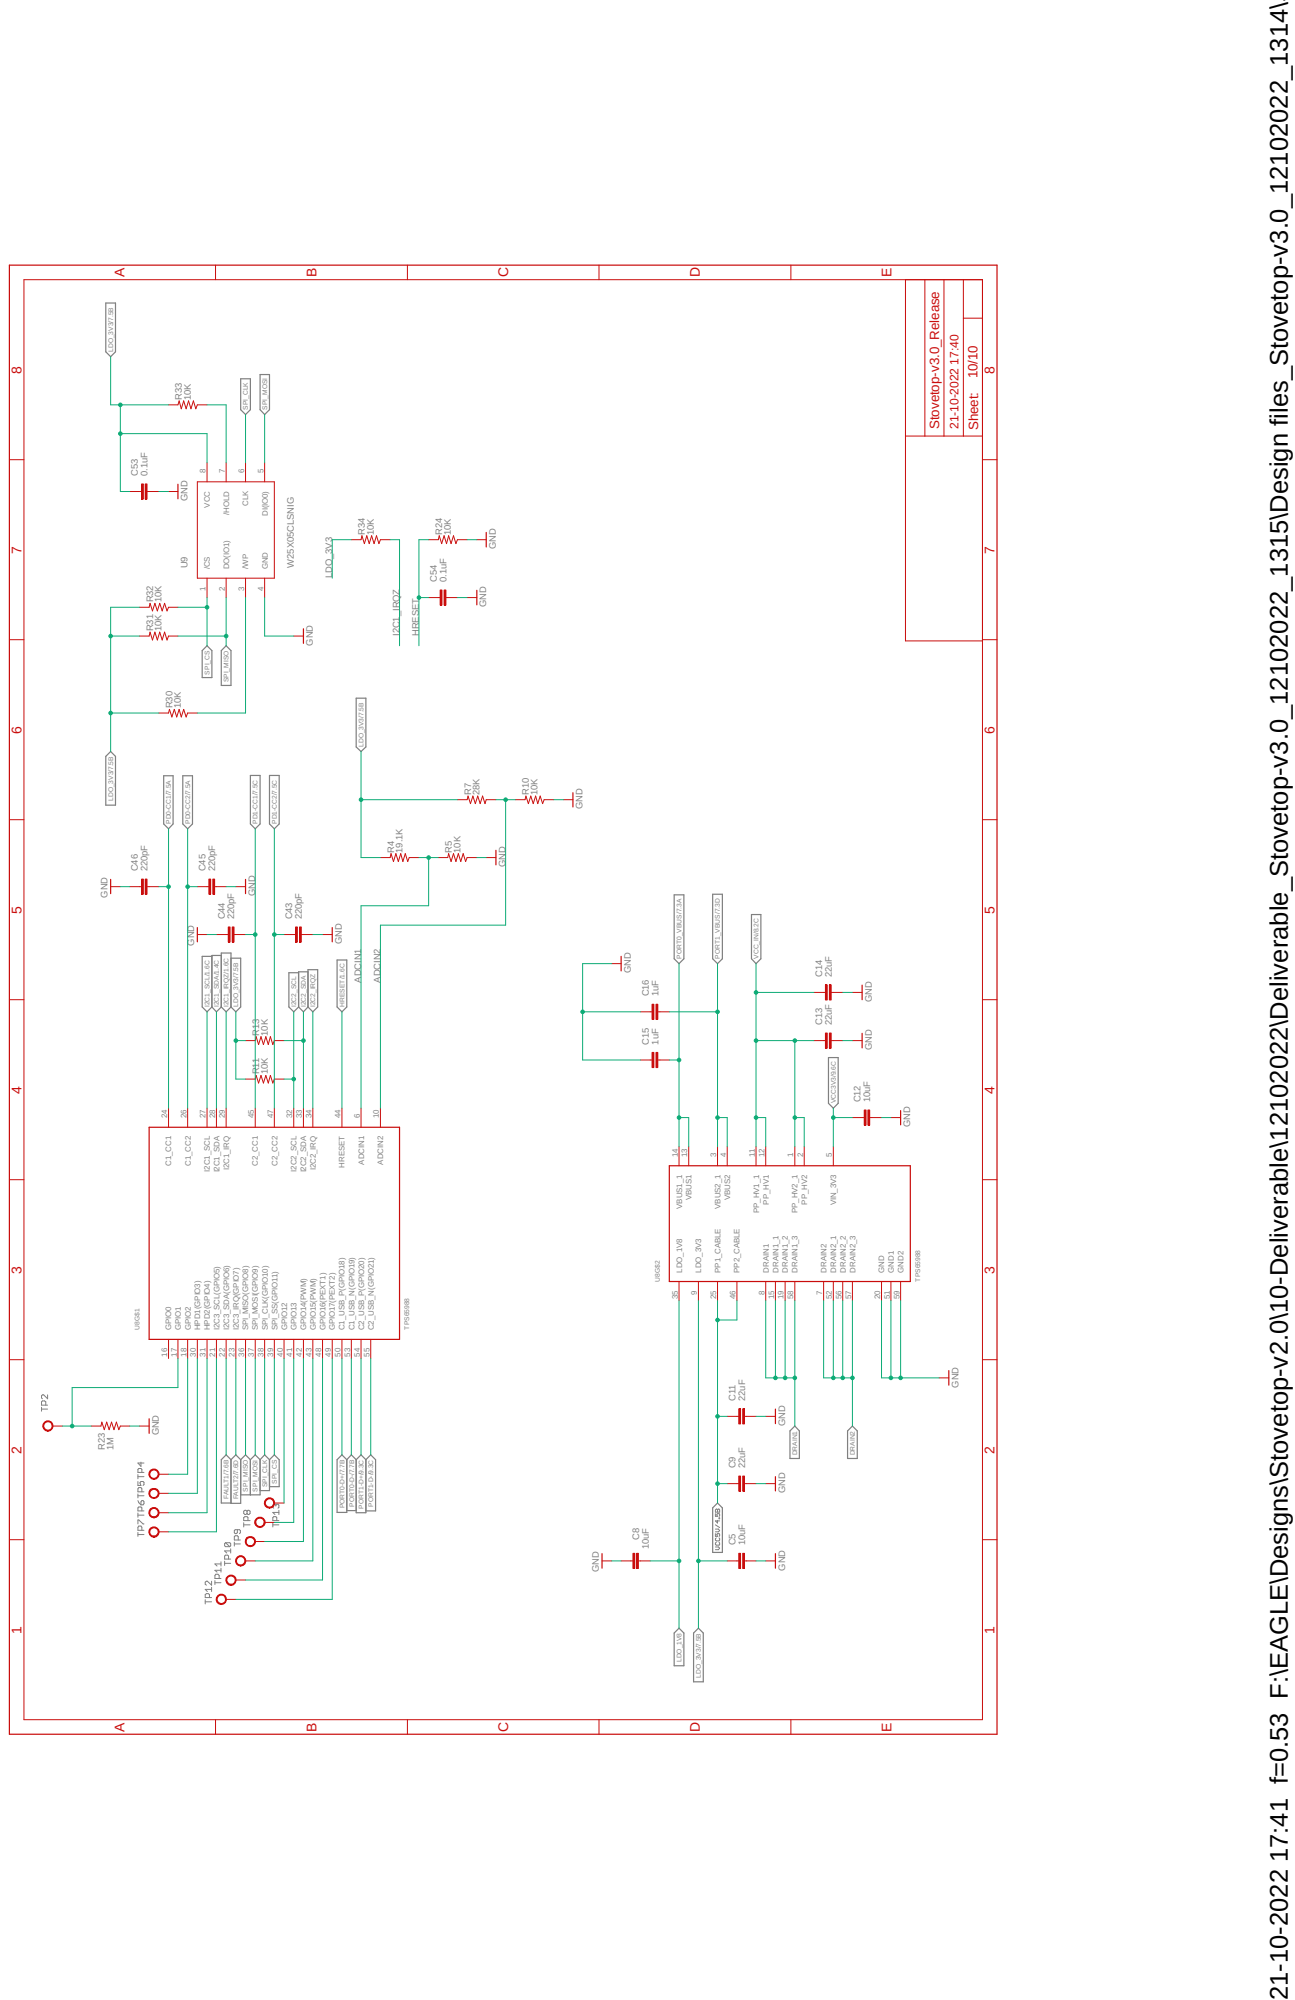
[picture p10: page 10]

21-10-2022 17:41 f=0.53 F:\EAGLE\Designs\Stovetop-v2.0\10-Deliverable\12102022\Deliverable_Stovetop-v3.0_12102022_1315\Design files_Stovetop-v3.0_12102022_1314\Stovetop-v3.0_Release.sch (Sheet: 10/10)

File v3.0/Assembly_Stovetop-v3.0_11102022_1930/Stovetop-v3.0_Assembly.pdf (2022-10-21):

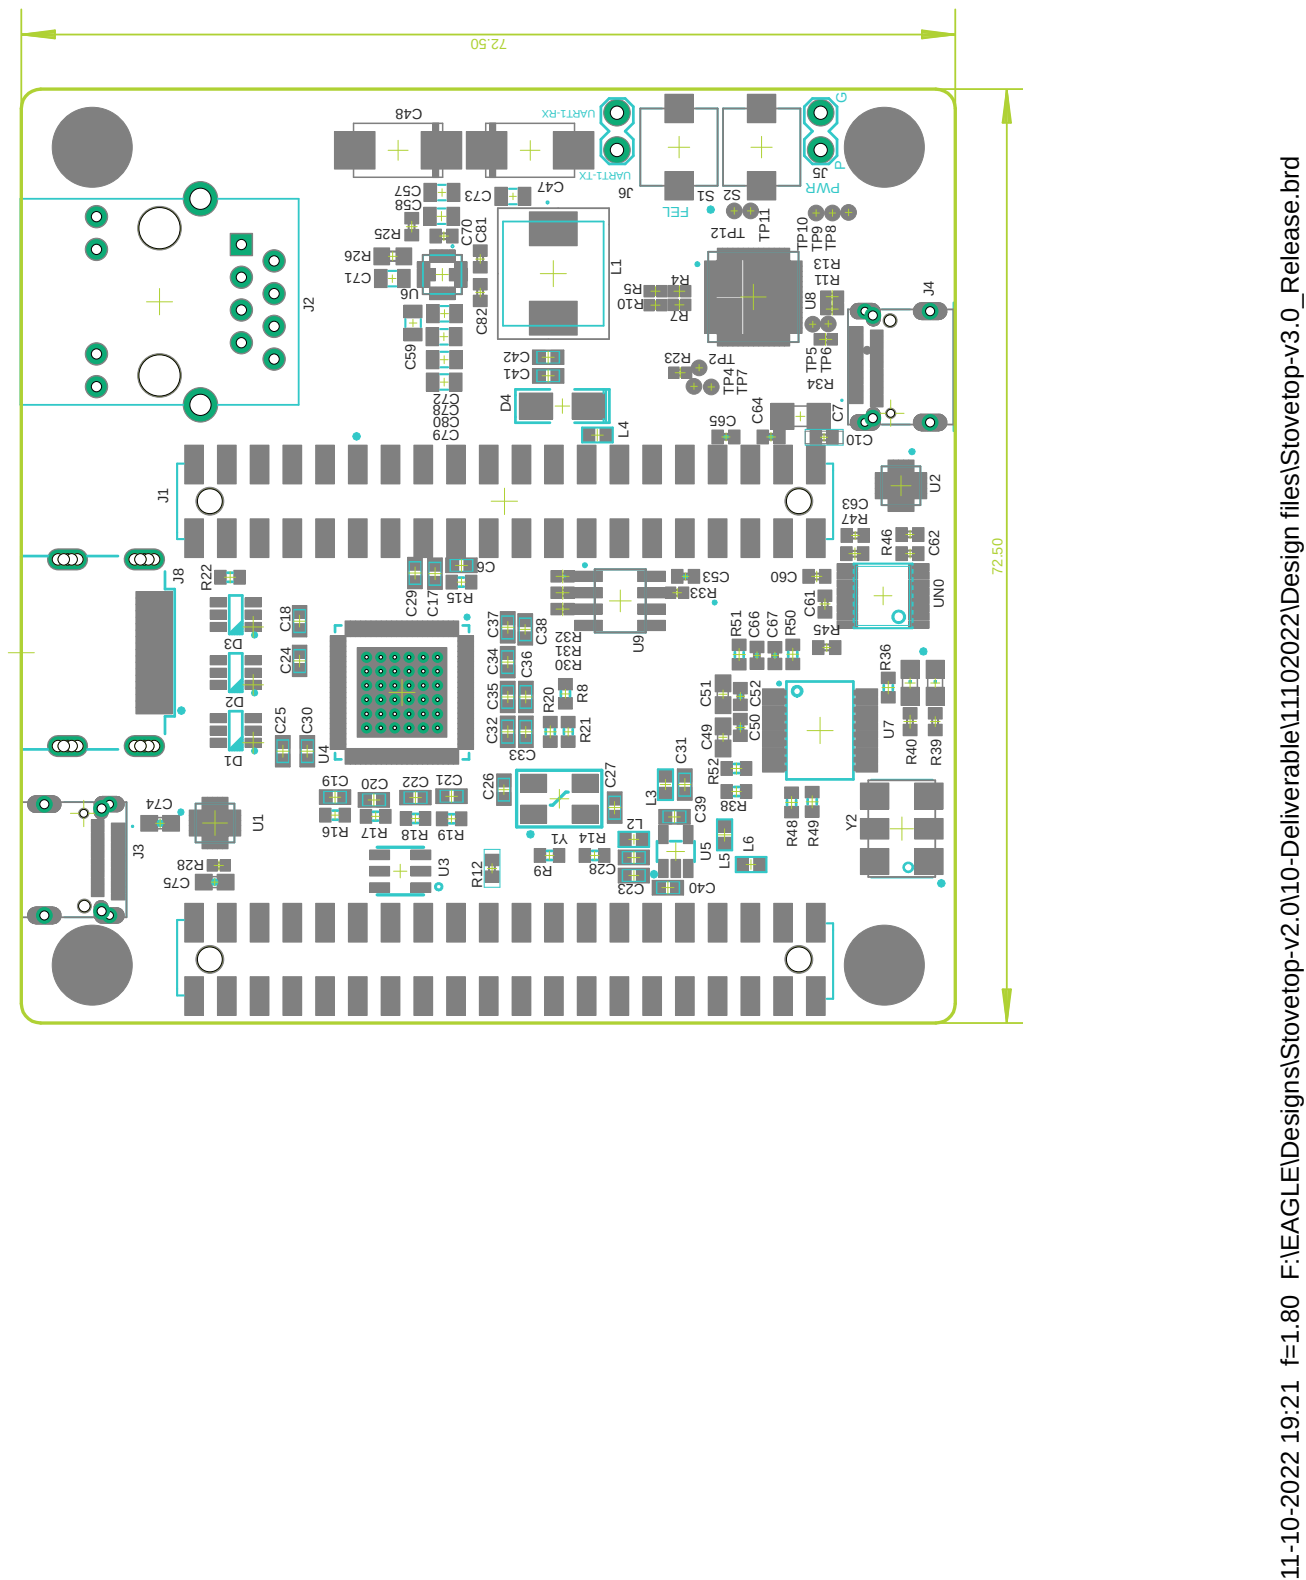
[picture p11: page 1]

11-10-2022 19:21 f=1.80 F:\EAGLE\Designs\Stovetop-v2.0\10-Deliverable\11102022\Design files\Stovetop-v3.0_Release.brd

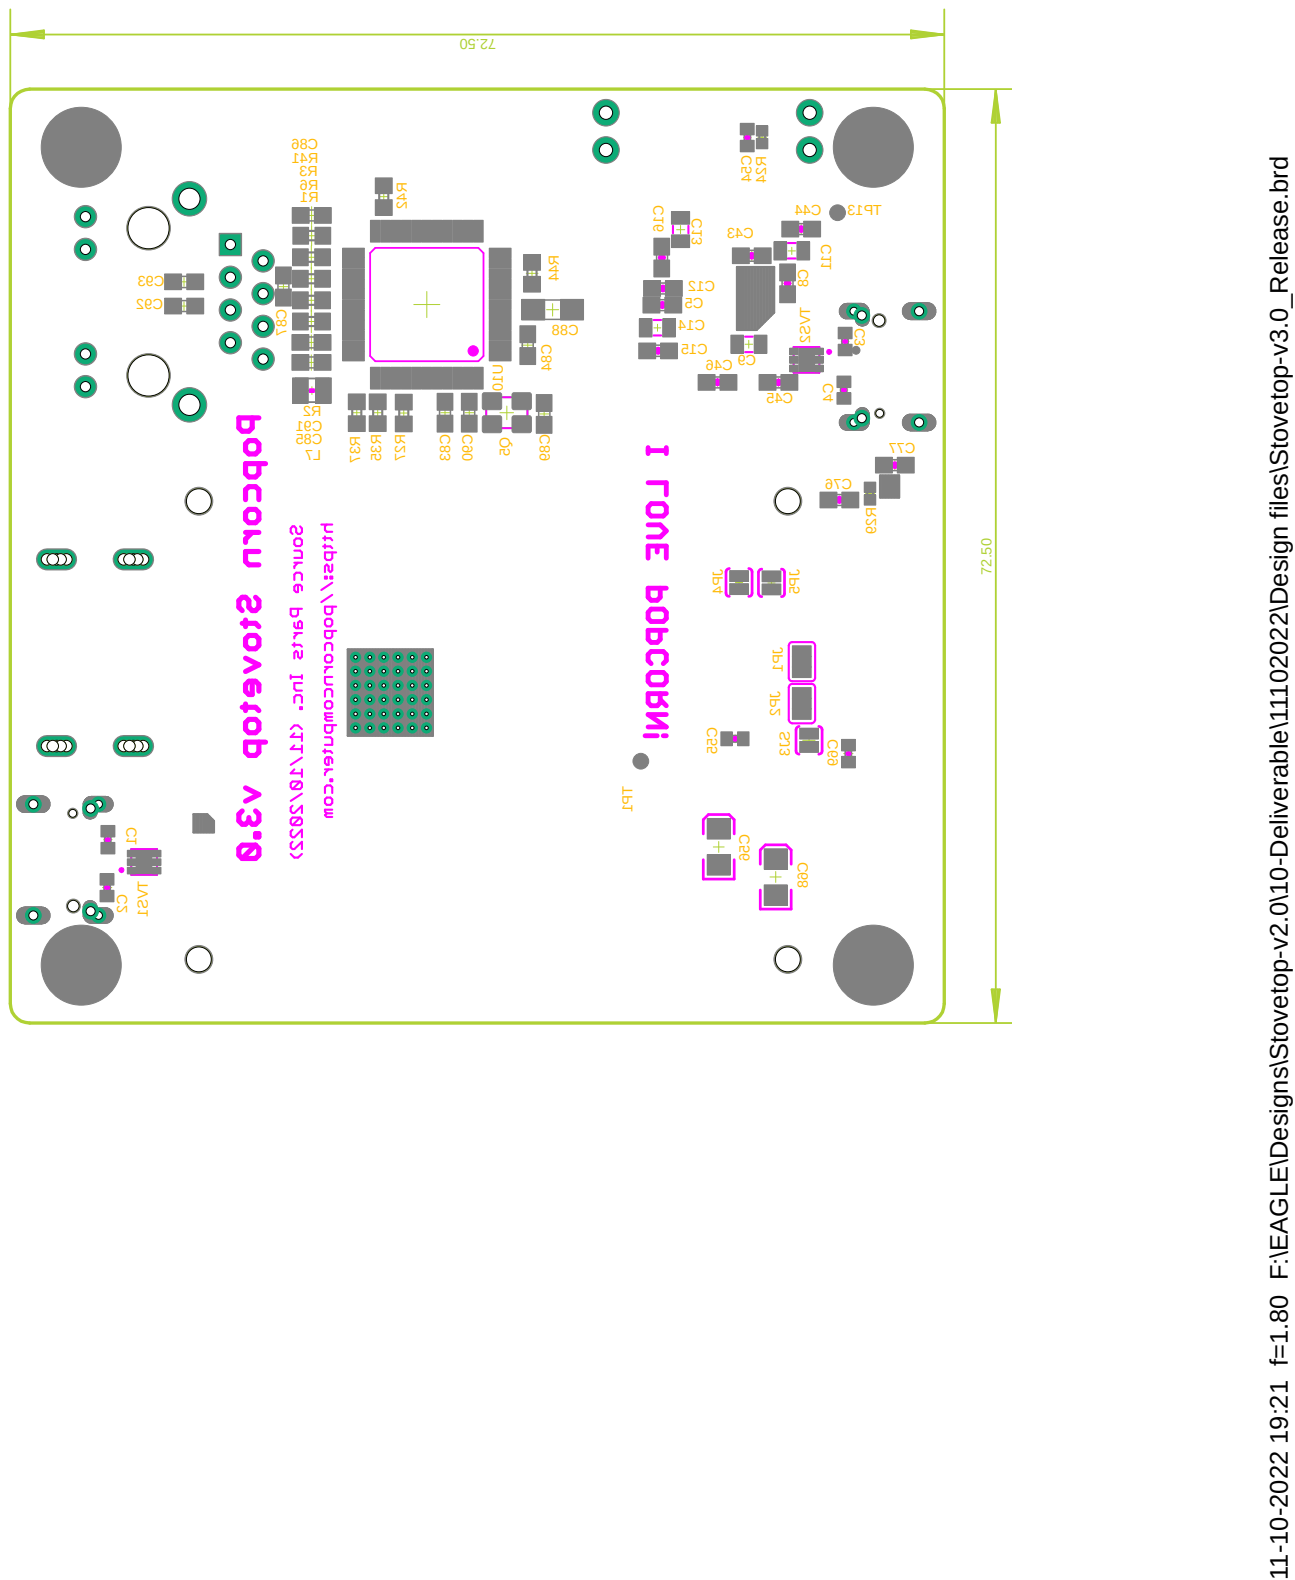
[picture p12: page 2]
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

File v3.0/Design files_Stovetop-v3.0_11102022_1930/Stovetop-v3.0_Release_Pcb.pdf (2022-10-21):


11-10-2022 19:18 f=1.80 F:\EAGLE\Designs\Stovetop-v2.0\10-Deliverable\11102022\Design files\Stovetop-v3.0_Release.brd

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


11-10-2022 19:19 f=1.80 F:\EAGLE\Designs\Stovetop-v2.0\10-Deliverable\11102022\Design files\Stovetop-v3.0_Release.brd

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


11-10-2022 19:20 f=1.80 F:\EAGLE\Designs\Stovetop-v2.0\10-Deliverable\11102022\Design files\Stovetop-v3.0_Release.brd

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

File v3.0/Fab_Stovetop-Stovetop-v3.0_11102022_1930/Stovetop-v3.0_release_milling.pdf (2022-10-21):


11-10-2022 19:23 f=1.80 F:\EAGLE\Designs\Stovetop-v2.0\10-Deliverable\11102022\Design files\Stovetop-v3.0_Release.brd

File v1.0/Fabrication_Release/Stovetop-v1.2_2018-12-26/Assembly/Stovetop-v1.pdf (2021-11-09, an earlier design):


12/21/2018 5:31 PM f=2.50 E:\Popcorn\Popcorn-Hardware\Stovetop\PCB\Stovetop-v1.brd

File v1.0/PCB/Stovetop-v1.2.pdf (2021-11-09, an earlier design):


1/16/2019 12:42 PM f=0.69 E:\Popcorn\Popcorn-Hardware\Stovetop\PCB\Stovetop-v1.2.sch (Sheet: 1/9)


1/16/2019 12:42 PM f=1.07 E:\Popcorn\Popcorn-Hardware\Stovetop\PCB\Stovetop-v1.2.sch (Sheet: 2/9)


1/16/2019 12:42 PM f=0.62 E:\Popcorn\Popcorn-Hardware\Stovetop\PCB\Stovetop-v1.2.sch (Sheet: 3/9)


1/16/2019 12:42 PM f=1.07 E:\Popcorn\Popcorn-Hardware\Stovetop\PCB\Stovetop-v1.2.sch (Sheet: 4/9)


1/16/2019 12:42 PM f=0.62 E:\Popcorn\Popcorn-Hardware\Stovetop\PCB\Stovetop-v1.2.sch (Sheet: 5/9)


1/16/2019 12:42 PM f=0.62 E:\Popcorn\Popcorn-Hardware\Stovetop\PCB\Stovetop-v1.2.sch (Sheet: 6/9)


1/16/2019 12:42 PM f=0.95 E:\Popcorn\Popcorn-Hardware\Stovetop\PCB\Stovetop-v1.2.sch (Sheet: 7/9)


1/16/2019 12:42 PM f=0.62 E:\Popcorn\Popcorn-Hardware\Stovetop\PCB\Stovetop-v1.2.sch (Sheet: 8/9)


1/16/2019 12:42 PM f=1.07 E:\Popcorn\Popcorn-Hardware\Stovetop\PCB\Stovetop-v1.2.sch (Sheet: 9/9)

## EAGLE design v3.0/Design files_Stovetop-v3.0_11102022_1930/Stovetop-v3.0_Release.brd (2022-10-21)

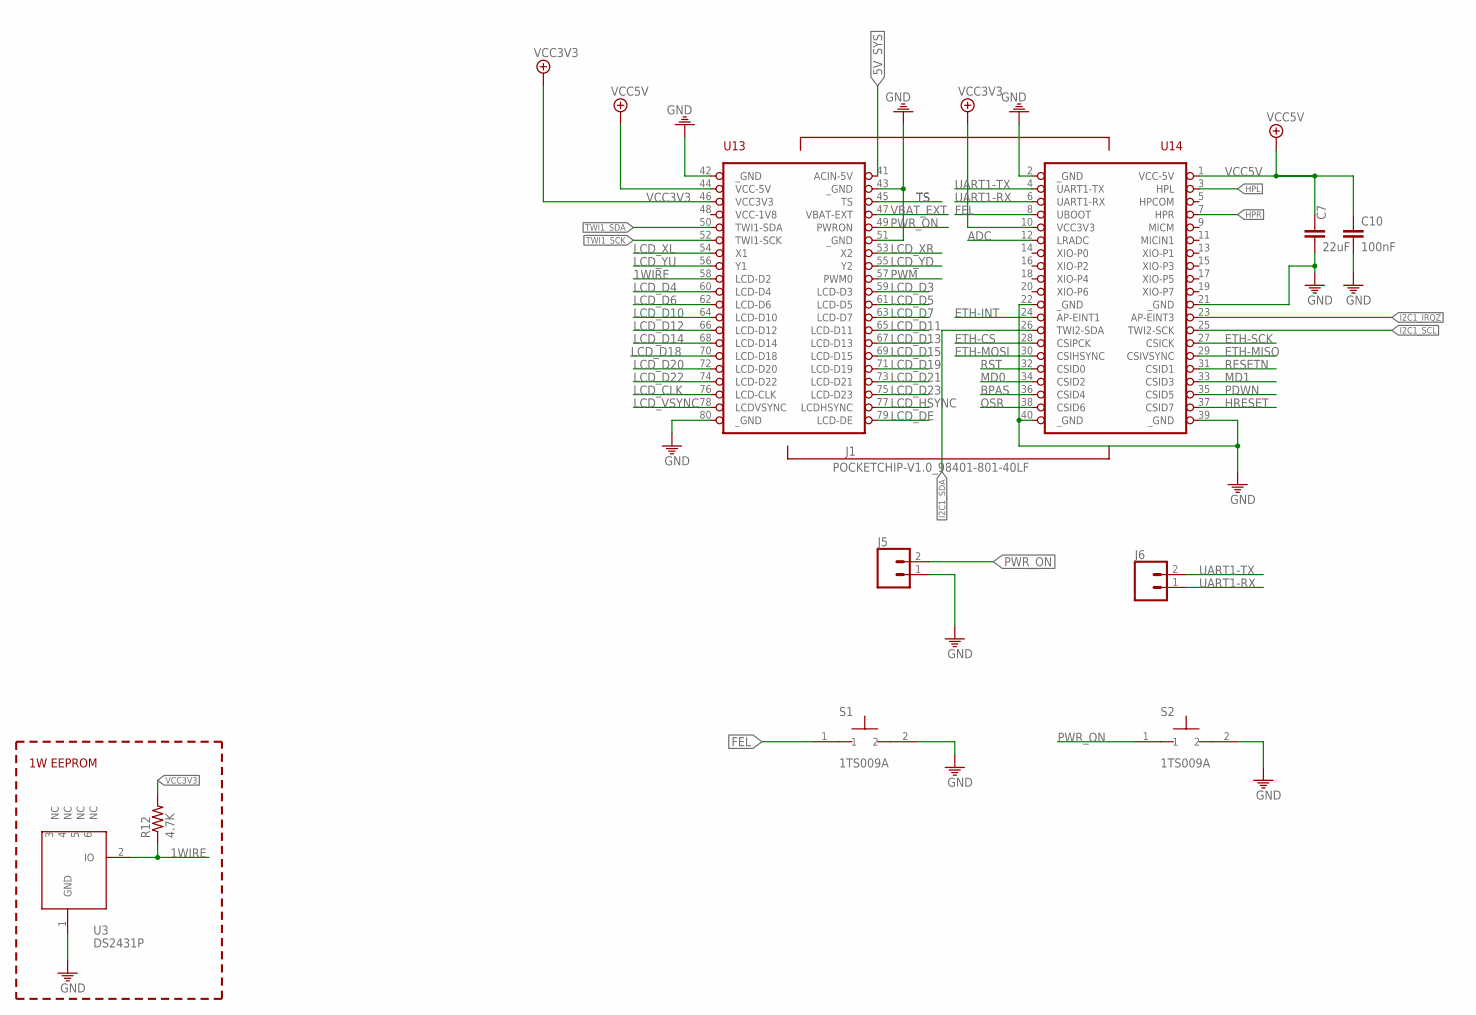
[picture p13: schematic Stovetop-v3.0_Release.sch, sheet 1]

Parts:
C7: 22uF; C1206
C10: 100nF; C0402
J1: POCKETCHIP-V1.0_98401-801-40LF
J5, J6: CONN_02LOCK; 1X02_LOCK
R12: 4.7K; R0402
S1, S2: 1TS009A
U3: DS2431P; TSOC6

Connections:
1WIRE: J1.58 (LCD-D2), R12.1, U3.2 (IO)
5V_SYS: J1.41 (ACIN-5V); also elsewhere on the board
ADC: J1.12 (LRADC)
BPAS: J1.36 (CSID4); also elsewhere on the board
ETH-CS: J1.28 (CSIPCK); also elsewhere on the board
ETH-INT: J1.24 (AP-EINT1); also elsewhere on the board
ETH-MISO: J1.29 (CSIVSYNC); also elsewhere on the board
ETH-MOSI: J1.30 (CSIHSYNC); also elsewhere on the board
ETH-SCK: J1.27 (CSICK); also elsewhere on the board
FEL: J1.8 (UBOOT), S1.1
GND: C7.2, C10.2, J1.2 (_GND), J1.21 (_GND), J1.22 (_GND), J1.39 (_GND), J1.40 (_GND), J1.42 (_GND), J1.43 (_GND), J1.51 (_GND), J1.80 (_GND), J5.1, S1.2, S2.2, U3.1 (GND); also elsewhere on the board
HPL: J1.3 (HPL); also elsewhere on the board
HPR: J1.7 (HPR); also elsewhere on the board
HRESET: J1.37 (CSID7); also elsewhere on the board
I2C1_IRQZ: J1.23 (AP-EINT3); also elsewhere on the board
I2C1_SCL: J1.25 (TWI2-SCK); also elsewhere on the board
I2C1_SDA: J1.26 (TWI2-SDA); also elsewhere on the board
LCD_CLK: J1.76 (LCD-CLK); also elsewhere on the board
LCD_D3: J1.59 (LCD-D3); also elsewhere on the board
LCD_D4: J1.60 (LCD-D4); also elsewhere on the board
LCD_D5: J1.61 (LCD-D5); also elsewhere on the board
LCD_D6: J1.62 (LCD-D6); also elsewhere on the board
LCD_D7: J1.63 (LCD-D7); also elsewhere on the board
LCD_D10: J1.64 (LCD-D10); also elsewhere on the board
LCD_D11: J1.65 (LCD-D11); also elsewhere on the board
LCD_D12: J1.66 (LCD-D12); also elsewhere on the board
LCD_D13: J1.67 (LCD-D13); also elsewhere on the board
LCD_D14: J1.68 (LCD-D14); also elsewhere on the board
LCD_D15: J1.69 (LCD-D15); also elsewhere on the board
LCD_D18: J1.70 (LCD-D18); also elsewhere on the board
LCD_D19: J1.71 (LCD-D19); also elsewhere on the board
LCD_D20: J1.72 (LCD-D20); also elsewhere on the board
LCD_D21: J1.73 (LCD-D21); also elsewhere on the board
LCD_D22: J1.74 (LCD-D22); also elsewhere on the board
LCD_D23: J1.75 (LCD-D23); also elsewhere on the board
LCD_DE: J1.79 (LCD-DE); also elsewhere on the board
LCD_HSYNC: J1.77 (LCDHSYNC); also elsewhere on the board
LCD_VSYNC: J1.78 (LCDVSYNC); also elsewhere on the board
LCD_XL: J1.54 (X1)
LCD_XR: J1.53 (X2)
LCD_YD: J1.55 (Y2)
LCD_YU: J1.56 (Y1)
MD0: J1.34 (CSID2); also elsewhere on the board
MD1: J1.33 (CSID3); also elsewhere on the board
OSR: J1.38 (CSID6); also elsewhere on the board
PDWN: J1.35 (CSID5); also elsewhere on the board
PWM: J1.57 (PWM0)
PWR_ON: J1.49 (PWRON), J5.2, S2.1
RESETN: J1.31 (CSID1)
RST: J1.32 (CSID0); also elsewhere on the board
TS: J1.45 (TS)
TWI1_SCK: J1.52 (TWI1-SCK); also elsewhere on the board
TWI1_SDA: J1.50 (TWI1-SDA); also elsewhere on the board
UART1-RX: J1.6 (UART1-RX), J6.1; also elsewhere on the board
UART1-TX: J1.4 (UART1-TX), J6.2; also elsewhere on the board
VBAT_EXT: J1.47 (VBAT-EXT)
VCC3V3: J1.10 (VCC3V3), J1.46 (VCC3V3), R12.2; also elsewhere on the board
VCC5V: C7.1, C10.1, J1.1 (VCC-5V), J1.44 (VCC-5V); also elsewhere on the board

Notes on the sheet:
1W EEPROM

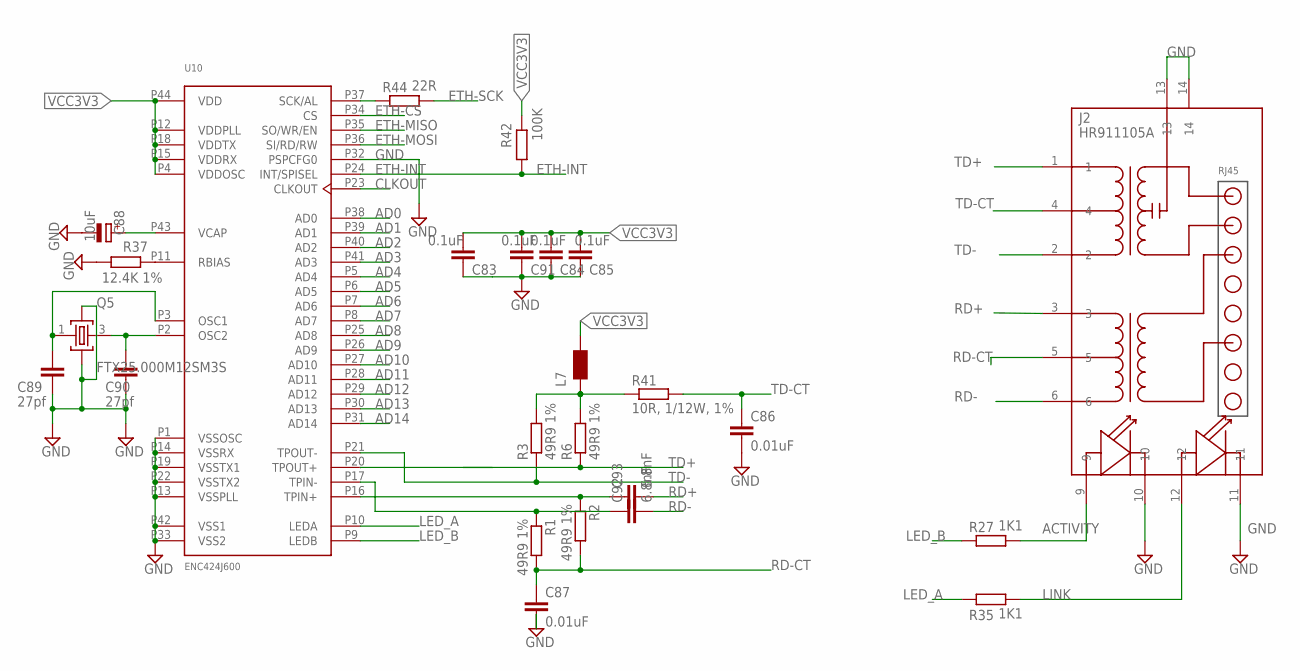
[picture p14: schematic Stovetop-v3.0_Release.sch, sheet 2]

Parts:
C83, C84, C85, C91: 0.1uF; C0603
C86, C87: 0.01uF; C0603
C88: 10uF; SMC_A
C89, C90: 27pf; C0603
C92, C93: 6.8nF; C0603
J2: HR911105A
L7: WE-KIL_0805; WE-KI_0805_B
Q5: FTX25.000M12SM3S; CRISTALLI_CRYSTAL3.2X2.5
R1, R2, R3, R6: 49R9 1%; R0603
R27, R35: 1K1; R0603
R37: 12.4K 1%; R0603
R41: 10R, 1/12W, 1%; R0603
R42: 100K; R0603
R44: 22R; R0603
U10: ENC424J600; TQFP44

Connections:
ACTIVITY: J2.9, R27.2
AD0: U10.P38 (AD0)
AD1: U10.P39 (AD1)
AD2: U10.P40 (AD2)
AD3: U10.P41 (AD3)
AD4: U10.P5 (AD4)
AD5: U10.P6 (AD5)
AD6: U10.P7 (AD6)
AD7: U10.P8 (AD7)
AD8: U10.P25 (AD8)
AD9: U10.P26 (AD9)
AD10: U10.P27 (AD10)
AD11: U10.P28 (AD11)
AD12: U10.P29 (AD12)
AD13: U10.P30 (AD13)
AD14: U10.P31 (AD14)
CCT: L7.2 (1), R3.2, R6.2, R41.1
CLKOUT: U10.P23 (CLKOUT)
DSFGDF: C92.1, R1.1, U10.P17 (TPIN-)
DSGDFSG: C93.1, R2.1, U10.P16 (TPIN+)
ETH-CS: U10.P34 (CS); also elsewhere on the board
ETH-INT: R42.2, U10.P24 (INT/SPISEL); also elsewhere on the board
ETH-MISO: U10.P35 (SO/WR/EN); also elsewhere on the board
ETH-MOSI: U10.P36 (SI/RD/RW); also elsewhere on the board
ETH-SCK: R44.2; also elsewhere on the board
GND: C83.2, C84.2, C85.2, C86.2, C87.2, C88.-, C89.2, C90.2, C91.2, J2.10, J2.11, J2.13, J2.14, Q5.2, Q5.4, R37.2, U10.P1 (VSSOSC), U10.P13 (VSSPLL), U10.P14 (VSSRX), U10.P19 (VSSTX1), U10.P22 (VSSTX2), U10.P32 (PSPCFG0), U10.P33 (VSS2), U10.P42 (VSS1); also elsewhere on the board
LED_A: R35.1, U10.P10 (LEDA)
LED_B: R27.1, U10.P9 (LEDB)
LINK: J2.12, R35.2
unnamed: R44.1, U10.P37 (SCK/AL)
unnamed: C88.+, U10.P43 (VCAP)
unnamed: R37.1, U10.P11 (RBIAS)
unnamed: C89.1, Q5.1, U10.P3 (OSC1)
unnamed: C90.1, Q5.3, U10.P2 (OSC2)
RD+: C93.2, J2.3
RD-: C92.2, J2.6
RD-CT: C87.1, J2.5, R1.2, R2.2
TD+: J2.1, R6.1, U10.P20 (TPOUT+)
TD-: J2.2, R3.1, U10.P21 (TPOUT-)
TD-CT: C86.1, J2.4, R41.2
VCC3V3: C83.1, C84.1, C85.1, C91.1, L7.1 (2), R42.1, U10.P4 (VDDOSC), U10.P12 (VDDPLL), U10.P15 (VDDRX), U10.P18 (VDDTX), U10.P44 (VDD); also elsewhere on the board

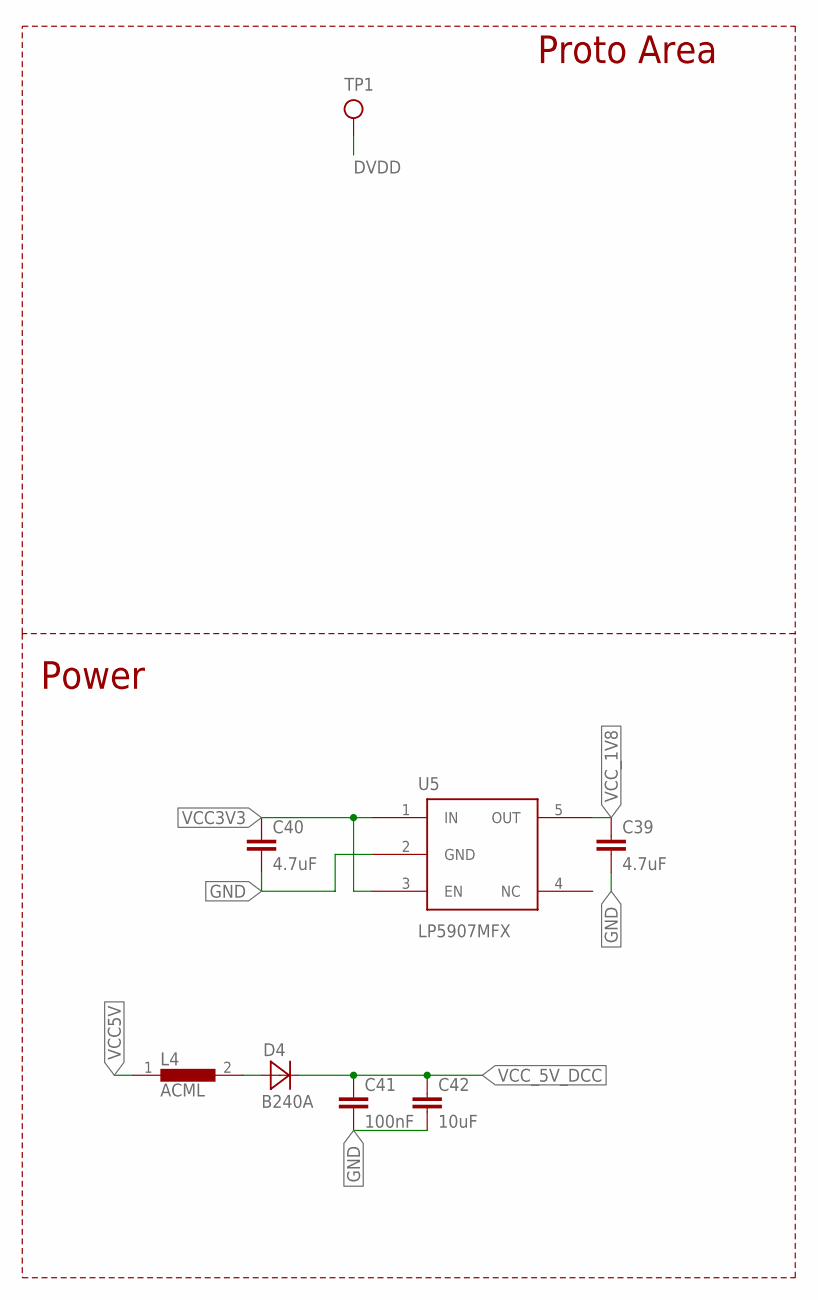
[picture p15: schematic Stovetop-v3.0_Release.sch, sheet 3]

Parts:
C39, C40: 4.7uF; 1608_0603
C41: 100nF; 1608_0603
C42: 10uF; 1608_0603
D4: B240A; SMA
L4: ACML; 0603
TP1: CHIP_HDMI_TEST_POINT; CHIP_HDMI_TP-1MMX1MM
U5: LP5907MFX; SOT23-5

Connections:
DVDD: TP1.0; also elsewhere on the board
GND: C39.2, C40.2, C41.2, C42.2, U5.2 (GND); also elsewhere on the board
unnamed: D4.1 (A), L4.2
VCC3V3: C40.1, U5.1 (IN), U5.3 (EN); also elsewhere on the board
VCC5V: L4.1; also elsewhere on the board
VCC_1V8: C39.1, U5.5 (OUT); also elsewhere on the board
VCC_5V_DCC: C41.1, C42.1, D4.2 (C); also elsewhere on the board

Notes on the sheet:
Proto Area
Power

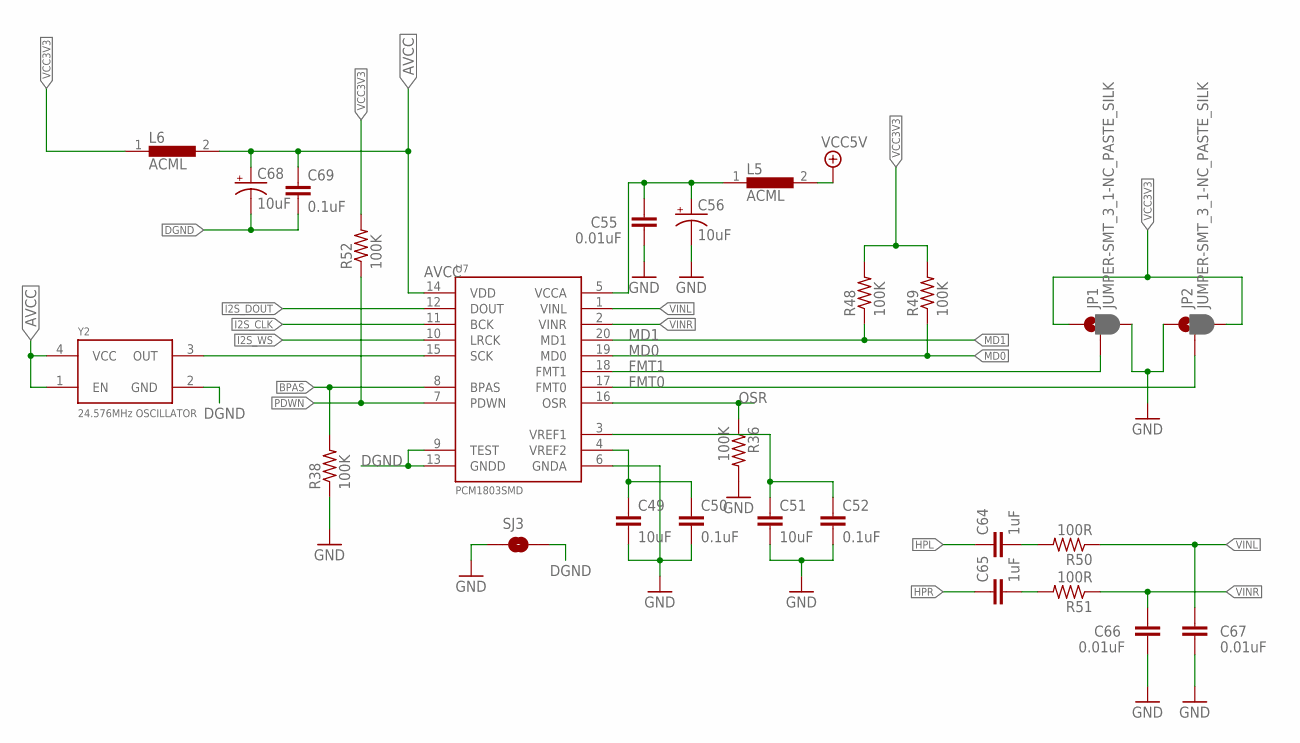
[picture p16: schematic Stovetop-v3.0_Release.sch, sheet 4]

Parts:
C49, C51: 10uF; 0603
C50, C52, C69: 0.1uF; 0402-CAP
C55, C66, C67: 0.01uF; 0402-CAP
C56, C68: 10uF; EIA3216
C64, C65: 1uF; 0402-CAP
JP1, JP2: JUMPER-SMT_3_1-NC_PASTE_SILK; SMT-JUMPER_3_1-NC_PASTE_SILK
L5, L6: ACML; 0603
R36, R38, R48, R49, R52: 100K; J1-0603
R50, R51: 100R; J1-0603
SJ3: SPARKFUN_SOLDERJUMPERTRACE; SPARKFUN_SJ_2S-TRACE
U7: PCM1803SMD; SSOP20
Y2: 24.576MHz OSCILLATOR; CRYSTAL-SMD-7.5X5.2-6PIN

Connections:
AVCC: C68.A (+), C69.1, L6.2, U7.14 (VDD), Y2.1 (EN), Y2.4 (VCC)
BPAS: R38.2, U7.8 (BPAS); also elsewhere on the board
DGND: C68.C (-), C69.2, SJ3.2, U7.9 (TEST), U7.13 (GNDD), Y2.2 (GND)
FMT0: JP2.2, U7.17 (FMT0)
FMT1: JP1.2, U7.18 (FMT1)
GND: C49.2, C50.2, C51.2, C52.2, C55.1, C56.C (-), C66.1, C67.1, JP1.3, JP2.1, R36.2, R38.1, SJ3.1, U7.6 (GNDA); also elsewhere on the board
HPL: C64.1; also elsewhere on the board
HPR: C65.1; also elsewhere on the board
I2S_CLK: U7.11 (BCK); also elsewhere on the board
I2S_DOUT: U7.12 (DOUT); also elsewhere on the board
I2S_WS: U7.10 (LRCK); also elsewhere on the board
MD0: R49.1, U7.19 (MD0); also elsewhere on the board
MD1: R48.1, U7.20 (MD1); also elsewhere on the board
unnamed: C49.1, C50.1, U7.4 (VREF2)
unnamed: C51.1, C52.1, U7.3 (VREF1)
unnamed: U7.15 (SCK), Y2.3 (OUT)
unnamed: C55.2, C56.A (+), L5.1, U7.5 (VCCA)
unnamed: C64.2, R50.2
unnamed: C65.2, R51.2
OSR: R36.1, U7.16 (OSR); also elsewhere on the board
PDWN: R52.1, U7.7 (PDWN); also elsewhere on the board
VCC3V3: JP1.1, JP2.3, L6.1, R48.2, R49.2, R52.2; also elsewhere on the board
VCC5V: L5.2; also elsewhere on the board
VINL: C67.2, R50.1, U7.1 (VINL)
VINR: C66.2, R51.1, U7.2 (VINR)

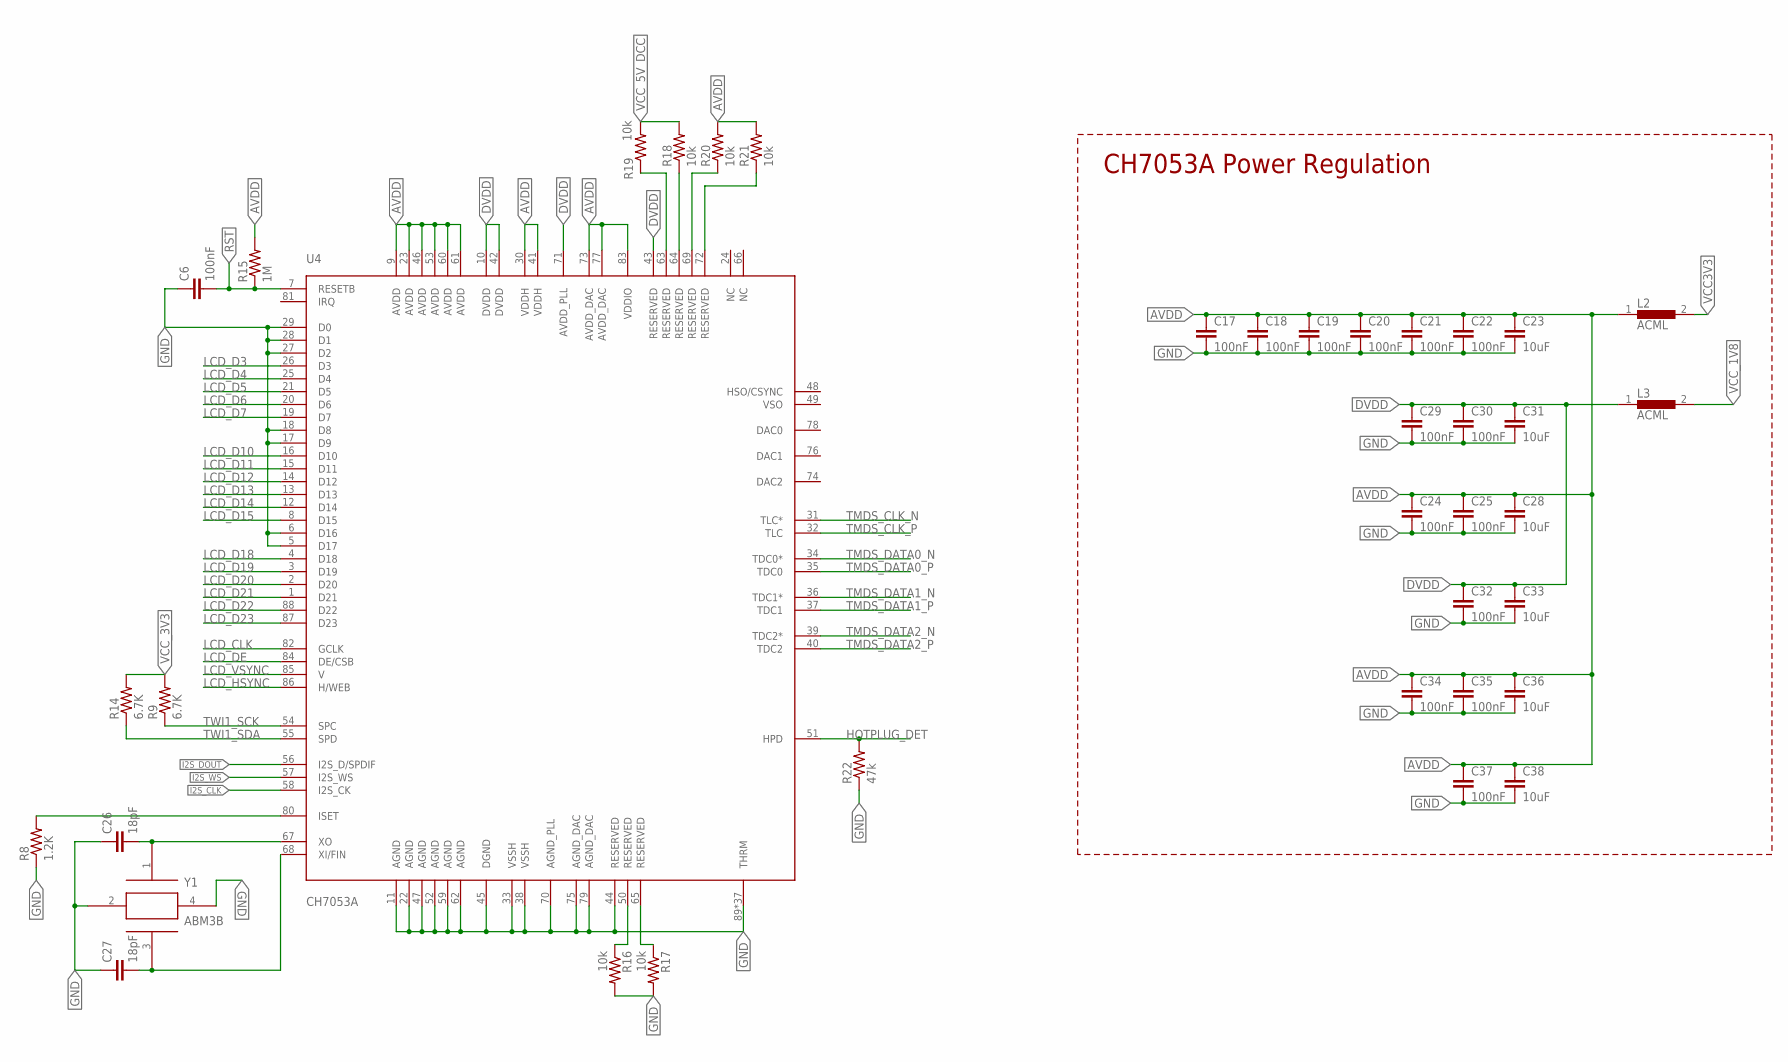
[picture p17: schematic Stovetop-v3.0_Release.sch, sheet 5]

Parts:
C6, C17, C18, C19, C20, C21, C22, C24, C25, C29, C30, C32, C34, C35, C37: 100nF; 1608_0603
C23, C28, C31, C33, C36, C38: 10uF; 1608_0603
C26, C27: 18pF; 1608_0603
L2, L3: ACML; 0603
R8: 1.2K; J1-0603
R9, R14: 6.7K; J1-0603
R15: 1M; J1-0603
R16, R17, R18, R19, R20, R21: 10k; J1-0603
R22: 47k; J1-0603
U4: CH7053A; QFN40P1000X1000X90_HS-89M
Y1: ABM3B

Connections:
AVDD: C17.1, C18.1, C19.1, C20.1, C21.1, C22.1, C23.1, C24.1, C25.1, C28.1, C34.1, C35.1, C36.1, C37.1, C38.1, L2.1, R15.2, R20.2, R21.2, U4.9 (AVDD), U4.23 (AVDD), U4.30 (VDDH), U4.41 (VDDH), U4.46 (AVDD), U4.53 (AVDD), U4.60 (AVDD), U4.61 (AVDD), U4.73 (AVDD_DAC), U4.77 (AVDD_DAC), U4.83 (VDDIO)
DVDD: C29.1, C30.1, C31.1, C32.1, C33.1, L3.1, U4.10 (DVDD), U4.42 (DVDD), U4.43 (RESERVED), U4.71 (AVDD_PLL); also elsewhere on the board
GND: C6.1, C17.2, C18.2, C19.2, C20.2, C21.2, C22.2, C23.2, C24.2, C25.2, C26.1, C27.1, C28.2, C29.2, C30.2, C31.2, C32.2, C33.2, C34.2, C35.2, C36.2, C37.2, C38.2, R8.1, R16.2, R17.2, R22.1, U4.5 (D17), U4.6 (D16), U4.11 (AGND), U4.17 (D9), U4.18 (D8), U4.22 (AGND), U4.27 (D2), U4.28 (D1), U4.29 (D0), U4.33 (VSSH), U4.38 (VSSH), U4.44 (RESERVED), U4.45 (DGND), U4.47 (AGND), U4.52 (AGND), U4.59 (AGND), U4.62 (AGND), U4.70 (AGND_PLL), U4.75 (AGND_DAC), U4.79 (AGND_DAC), U4.89 (THRM), U4.P$1 (THRM), U4.P$2 (THRM), U4.P$3 (THRM), U4.P$4 (THRM), U4.P$5 (THRM), U4.P$6 (THRM), U4.P$7 (THRM), U4.P$8 (THRM), U4.P$9 (THRM), U4.P$10 (THRM), U4.P$11 (THRM), U4.P$12 (THRM), U4.P$13 (THRM), U4.P$14 (THRM), U4.P$15 (THRM), U4.P$16 (THRM), U4.P$17 (THRM), U4.P$18 (THRM), U4.P$19 (THRM), U4.P$20 (THRM), U4.P$21 (THRM), U4.P$22 (THRM), U4.P$23 (THRM), U4.P$24 (THRM), U4.P$25 (THRM), U4.P$26 (THRM), U4.P$27 (THRM), U4.P$28 (THRM), U4.P$29 (THRM), U4.P$30 (THRM), U4.P$31 (THRM), U4.P$32 (THRM), U4.P$33 (THRM), U4.P$34 (THRM), U4.P$35 (THRM), U4.P$36 (THRM), Y1.2, Y1.4; also elsewhere on the board
HOTPLUG_DET: R22.2, U4.51 (HPD); also elsewhere on the board
I2S_CLK: U4.58 (I2S_CK); also elsewhere on the board
I2S_DOUT: U4.56 (I2S_D/SPDIF); also elsewhere on the board
I2S_WS: U4.57 (I2S_WS); also elsewhere on the board
LCD_CLK: U4.82 (GCLK); also elsewhere on the board
LCD_D3: U4.26 (D3); also elsewhere on the board
LCD_D4: U4.25 (D4); also elsewhere on the board
LCD_D5: U4.21 (D5); also elsewhere on the board
LCD_D6: U4.20 (D6); also elsewhere on the board
LCD_D7: U4.19 (D7); also elsewhere on the board
LCD_D10: U4.16 (D10); also elsewhere on the board
LCD_D11: U4.15 (D11); also elsewhere on the board
LCD_D12: U4.14 (D12); also elsewhere on the board
LCD_D13: U4.13 (D13); also elsewhere on the board
LCD_D14: U4.12 (D14); also elsewhere on the board
LCD_D15: U4.8 (D15); also elsewhere on the board
LCD_D18: U4.4 (D18); also elsewhere on the board
LCD_D19: U4.3 (D19); also elsewhere on the board
LCD_D20: U4.2 (D20); also elsewhere on the board
LCD_D21: U4.1 (D21); also elsewhere on the board
LCD_D22: U4.88 (D22); also elsewhere on the board
LCD_D23: U4.87 (D23); also elsewhere on the board
LCD_DE: U4.84 (DE/CSB); also elsewhere on the board
LCD_HSYNC: U4.86 (H/WEB); also elsewhere on the board
LCD_VSYNC: U4.85 (V); also elsewhere on the board
unnamed: C27.2, U4.68 (XI/FIN), Y1.3
unnamed: R8.2, U4.80 (ISET)
unnamed: R16.1, U4.50 (RESERVED)
unnamed: R17.1, U4.65 (RESERVED)
unnamed: R19.1, U4.63 (RESERVED)
unnamed: R18.1, U4.64 (RESERVED)
unnamed: R21.1, U4.72 (RESERVED)
unnamed: R20.1, U4.69 (RESERVED)
unnamed: C26.2, U4.67 (XO), Y1.1
RST: C6.2, R15.1, U4.7 (RESETB); also elsewhere on the board
TMDS_CLK_N: U4.31 (TLC*); also elsewhere on the board
TMDS_CLK_P: U4.32 (TLC); also elsewhere on the board
TMDS_DATA0_N: U4.34 (TDC0*); also elsewhere on the board
TMDS_DATA0_P: U4.35 (TDC0); also elsewhere on the board
TMDS_DATA1_N: U4.36 (TDC1*); also elsewhere on the board
TMDS_DATA1_P: U4.37 (TDC1); also elsewhere on the board
TMDS_DATA2_N: U4.39 (TDC2*); also elsewhere on the board
TMDS_DATA2_P: U4.40 (TDC2); also elsewhere on the board
TWI1_SCK: R9.1, U4.54 (SPC); also elsewhere on the board
TWI1_SDA: R14.1, U4.55 (SPD); also elsewhere on the board
VCC3V3: L2.2; also elsewhere on the board
VCC_1V8: L3.2; also elsewhere on the board
VCC_3V3: R9.2, R14.2
VCC_5V_DCC: R18.2, R19.2; also elsewhere on the board

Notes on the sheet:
CH7053A Power Regulation

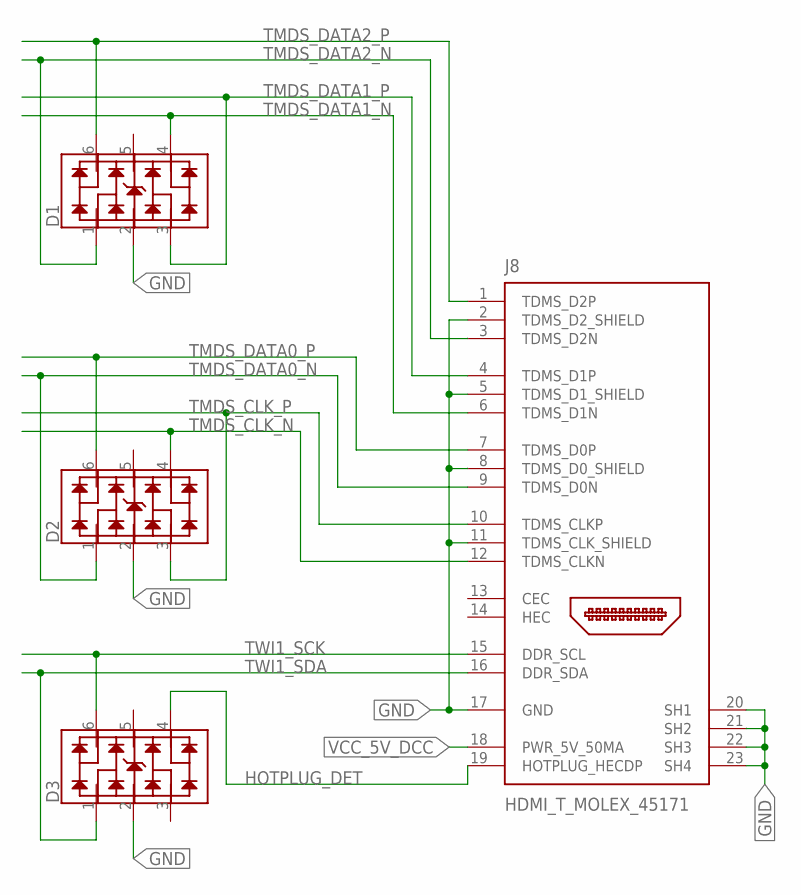
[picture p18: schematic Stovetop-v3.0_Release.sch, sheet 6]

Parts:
D1, D2, D3: D-SEMTECH-RCLAMP0504S; T_SOT95P285X90-6N
J8: HDMI_T_MOLEX_45171; CHIP_HDMI_T_MOLEX_45171

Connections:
GND: D1.2, D2.2, D3.2, J8.2 (TDMS_D2_SHIELD), J8.5 (TDMS_D1_SHIELD), J8.8 (TDMS_D0_SHIELD), J8.11 (TDMS_CLK_SHIELD), J8.17 (GND), J8.20 (SH1), J8.21 (SH2), J8.22 (SH3), J8.23 (SH4); also elsewhere on the board
HOTPLUG_DET: D3.4, J8.19 (HOTPLUG_HECDP); also elsewhere on the board
TMDS_CLK_N: D2.4, J8.12 (TDMS_CLKN); also elsewhere on the board
TMDS_CLK_P: D2.3, J8.10 (TDMS_CLKP); also elsewhere on the board
TMDS_DATA0_N: D2.1, J8.9 (TDMS_D0N); also elsewhere on the board
TMDS_DATA0_P: D2.6, J8.7 (TDMS_D0P); also elsewhere on the board
TMDS_DATA1_N: D1.4, J8.6 (TDMS_D1N); also elsewhere on the board
TMDS_DATA1_P: D1.3, J8.4 (TDMS_D1P); also elsewhere on the board
TMDS_DATA2_N: D1.1, J8.3 (TDMS_D2N); also elsewhere on the board
TMDS_DATA2_P: D1.6, J8.1 (TDMS_D2P); also elsewhere on the board
TWI1_SCK: D3.6, J8.15 (DDR_SCL); also elsewhere on the board
TWI1_SDA: D3.1, J8.16 (DDR_SDA); also elsewhere on the board
VCC_5V_DCC: J8.18 (PWR_5V_50MA); also elsewhere on the board

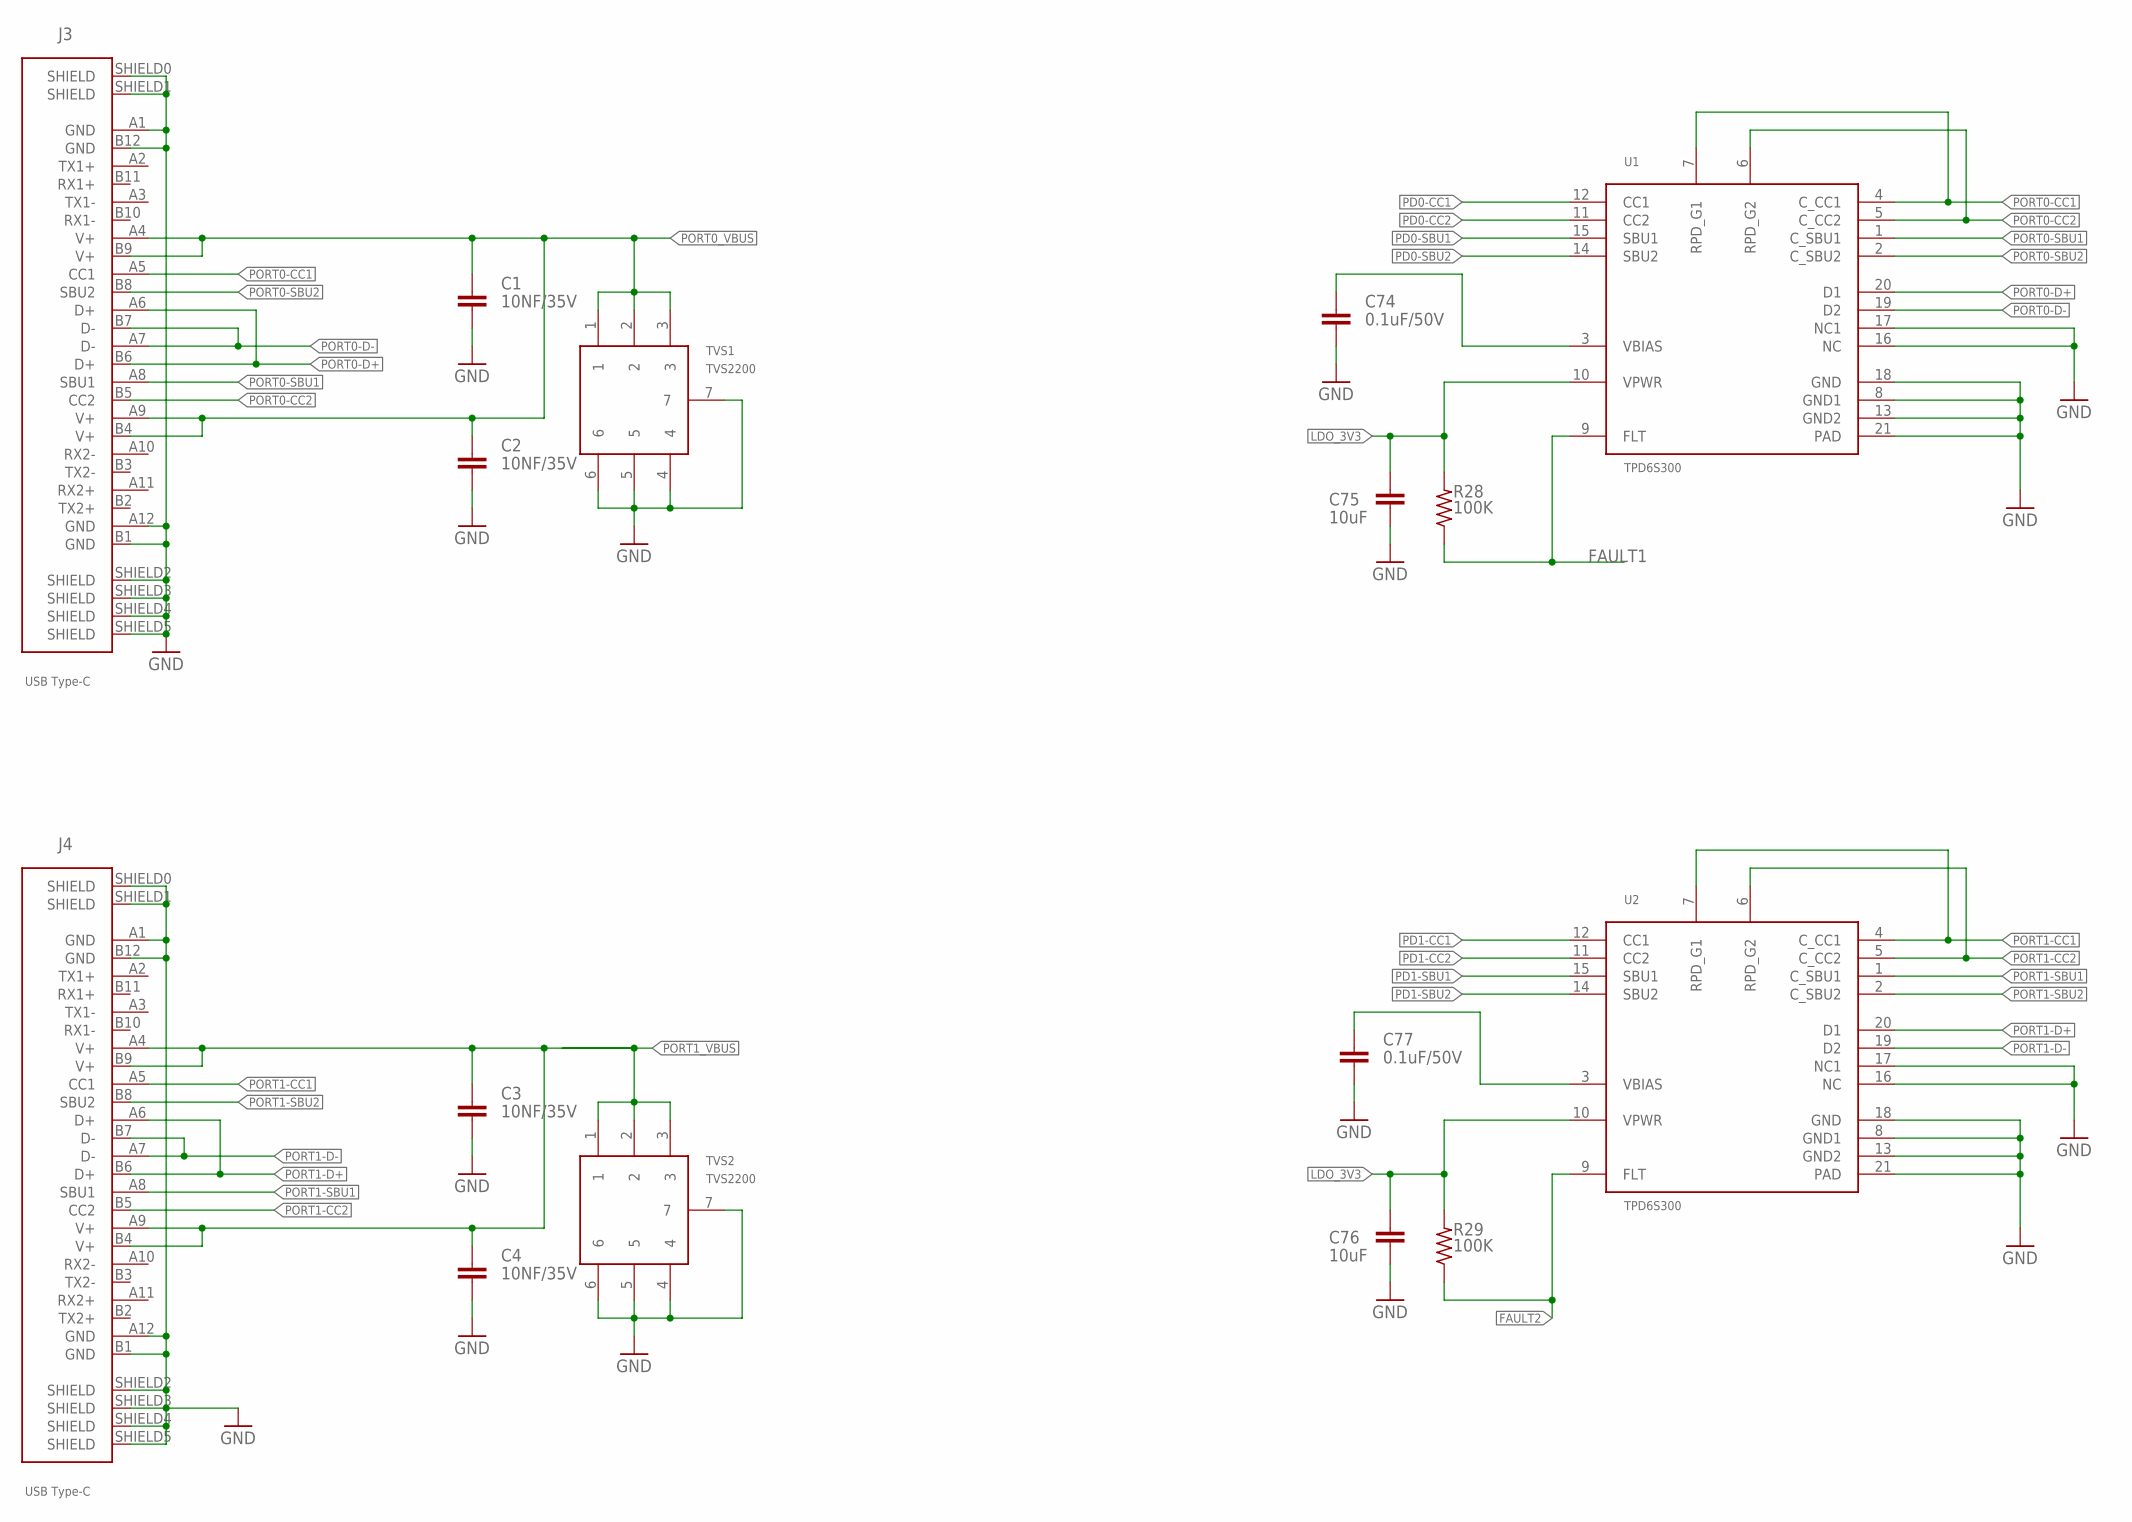
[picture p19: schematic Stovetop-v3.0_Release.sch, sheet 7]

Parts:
C1, C2, C3, C4: 10NF/35V; 0402-CAP
C74, C77: 0.1uF/50V; 0603-CAP
C75, C76: 10uF; 0603-CAP
J3, J4: STOVETOP-V2.0_03062020_1600_STOVETOP-V2.0_CHECK_T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; STOVETOP-V2.0_03062020_1600_STOVETOP-V2.0_CHECK_TRISTAN-ROB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
R28, R29: 100K; R0402
TVS1, TVS2: TVS2200
U1, U2: TPD6S300

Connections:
FAULT1: R28.1, U1.9 (FLT); also elsewhere on the board
FAULT2: R29.1, U2.9 (FLT); also elsewhere on the board
GND: C1.1, C2.1, C3.1, C4.1, C74.1, C75.1, C76.1, C77.1, J3.A1 (GND), J3.A12 (GND), J3.B1 (GND), J3.B12 (GND), J3.SHIELD0 (SHIELD), J3.SHIELD1 (SHIELD), J3.SHIELD2 (SHIELD), J3.SHIELD3 (SHIELD), J3.SHIELD4 (SHIELD), J3.SHIELD5 (SHIELD), J4.A1 (GND), J4.A12 (GND), J4.B1 (GND), J4.B12 (GND), J4.SHIELD0 (SHIELD), J4.SHIELD1 (SHIELD), J4.SHIELD2 (SHIELD), J4.SHIELD3 (SHIELD), J4.SHIELD4 (SHIELD), J4.SHIELD5 (SHIELD), TVS1.4, TVS1.5, TVS1.6, TVS1.7, TVS2.4, TVS2.5, TVS2.6, TVS2.7, U1.8 (GND1), U1.13 (GND2), U1.16 (NC), U1.17 (NC1), U1.18 (GND), U1.21 (PAD), U2.8 (GND1), U2.13 (GND2), U2.16 (NC), U2.17 (NC1), U2.18 (GND), U2.21 (PAD); also elsewhere on the board
LDO_3V3: C75.2, C76.2, R28.2, R29.2, U1.10 (VPWR), U2.10 (VPWR); also elsewhere on the board
unnamed: C74.2, U1.3 (VBIAS)
unnamed: C77.2, U2.3 (VBIAS)
PD0-CC1: U1.12 (CC1); also elsewhere on the board
PD0-CC2: U1.11 (CC2); also elsewhere on the board
PD0-SBU1: U1.15 (SBU1)
PD0-SBU2: U1.14 (SBU2)
PD1-CC1: U2.12 (CC1); also elsewhere on the board
PD1-CC2: U2.11 (CC2); also elsewhere on the board
PD1-SBU1: U2.15 (SBU1)
PD1-SBU2: U2.14 (SBU2)
PORT0-CC1: J3.A5 (CC1), U1.4 (C_CC1), U1.7 (RPD_G1)
PORT0-CC2: J3.B5 (CC2), U1.5 (C_CC2), U1.6 (RPD_G2)
PORT0-D+: J3.A6 (D+), J3.B6 (D+), U1.20 (D1); also elsewhere on the board
PORT0-D-: J3.A7 (D-), J3.B7 (D-), U1.19 (D2); also elsewhere on the board
PORT0-SBU1: J3.A8 (SBU1), U1.1 (C_SBU1)
PORT0-SBU2: J3.B8 (SBU2), U1.2 (C_SBU2)
PORT0_VBUS: C1.2, C2.2, J3.A4 (V+), J3.A9 (V+), J3.B4 (V+), J3.B9 (V+), TVS1.1, TVS1.2, TVS1.3; also elsewhere on the board
PORT1-CC1: J4.A5 (CC1), U2.4 (C_CC1), U2.7 (RPD_G1)
PORT1-CC2: J4.B5 (CC2), U2.5 (C_CC2), U2.6 (RPD_G2)
PORT1-D+: J4.A6 (D+), J4.B6 (D+), U2.20 (D1); also elsewhere on the board
PORT1-D-: J4.A7 (D-), J4.B7 (D-), U2.19 (D2); also elsewhere on the board
PORT1-SBU1: J4.A8 (SBU1), U2.1 (C_SBU1)
PORT1-SBU2: J4.B8 (SBU2), U2.2 (C_SBU2)
PORT1_VBUS: C3.2, C4.2, J4.A4 (V+), J4.A9 (V+), J4.B4 (V+), J4.B9 (V+), TVS2.1, TVS2.2, TVS2.3; also elsewhere on the board

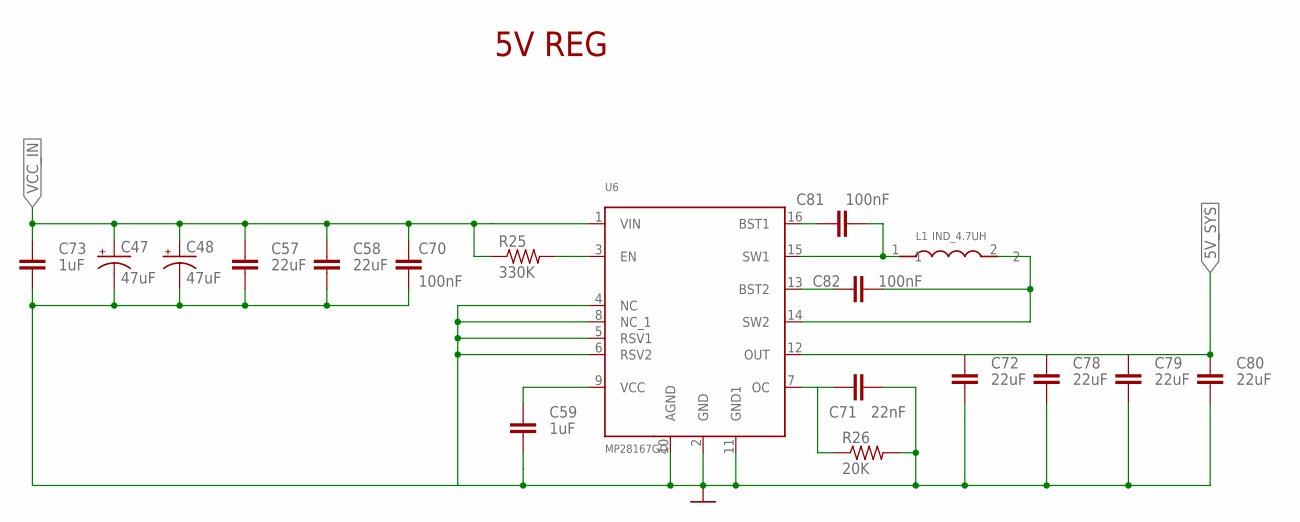
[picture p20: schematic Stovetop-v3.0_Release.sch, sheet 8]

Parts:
C47, C48: 47uF; D/7343-31W
C57, C58, C72, C78, C79, C80: 22uF; 0805
C59, C73: 1uF; 0805
C70, C81, C82: 100nF; C0402
C71: 22nF; 0805
L1: IND_4.7UH
R25: 330K; R0402
R26: 20K; R0603
U6: MP28167GQ

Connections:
5V_SYS: C72.2, C78.2, C79.2, C80.2, U6.12 (OUT); also elsewhere on the board
GND: C47.-, C48.-, C57.1, C58.1, C59.1, C70.2, C71.1, C72.1, C73.1, C78.1, C79.1, C80.1, R26.2, U6.2 (GND), U6.4 (NC), U6.5 (RSV1), U6.6 (RSV2), U6.8 (NC_1), U6.10 (AGND), U6.11 (GND1); also elsewhere on the board
unnamed: C71.2, R26.1, U6.7 (OC)
unnamed: R25.2, U6.3 (EN)
unnamed: C59.2, U6.9 (VCC)
unnamed: C81.1, U6.16 (BST1)
unnamed: C81.2, L1.1, U6.15 (SW1)
unnamed: C82.1, U6.13 (BST2)
unnamed: C82.2, L1.2, U6.14 (SW2)
VCC_IN: C47.+, C48.+, C57.2, C58.2, C70.1, C73.2, R25.1, U6.1 (VIN); also elsewhere on the board

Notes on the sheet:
5V REG

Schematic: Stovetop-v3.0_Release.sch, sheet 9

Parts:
C60: 0.1uF; C0402
C61: 10uF; C0402
C62, C63: 47pF; C0402
JP4, JP5: JUMPER-PAD-2-NC_BY_TRACE; PAD-JUMPER-2-NC_BY_TRACE_YES_SILK
R39, R40: 1K; R0402
R45: 0; R0402
R46, R47: 27R; R0402
RX_LED: Blue; LED-805
TX_LED: Amber; LED-805
UN0: FT230XS; SSOP-16

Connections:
5V_SYS: C61.1, UN0.12 (VCC); also elsewhere on the board
GND: C60.2, C61.2, C62.2, C63.2, R45.1, UN0.5 (GND), UN0.13 (GND); also elsewhere on the board
unnamed: R47.1, UN0.9 (USBDM)
unnamed: R46.1, UN0.8 (USBDP)
unnamed: R45.2, UN0.16 (CBUS3)
unnamed: R39.2, RX_LED.A
unnamed: R40.2, TX_LED.A
PORT1-D+: C62.1, R46.2; also elsewhere on the board
PORT1-D-: C63.1, R47.2; also elsewhere on the board
RXD: JP5.1, UN0.4 (RXD)
RXLED: RX_LED.C, UN0.7 (CBUS2)
TXD: JP4.1, UN0.1 (TXD)
TXLED: TX_LED.C, UN0.14 (CBUS1)
UART1-RX: JP4.2; also elsewhere on the board
UART1-TX: JP5.2; also elsewhere on the board
VCC3V3: R39.1, R40.1; also elsewhere on the board
VCCIO: C60.1, UN0.3 (VCCIO), UN0.10 (3V3OUT), UN0.11 (!RESET)

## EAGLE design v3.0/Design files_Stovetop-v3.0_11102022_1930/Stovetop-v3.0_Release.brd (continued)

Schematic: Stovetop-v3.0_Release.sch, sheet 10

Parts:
C5, C8, C12: 10uF; 0603-CAP
C9, C11, C13, C14: 22uF; 0805
C15, C16: 1uF; 0603-CAP
C43, C44, C45, C46: 220pF; 0603-CAP
C53, C54: 0.1uF; 0402-CAP
R4: 19.1K; R0402
R5, R10, R11, R13, R24, R30, R31, R32, R33, R34: 10K; R0402
R7: 28K; R0402
R23: 1M; R0402
TP2, TP4, TP5, TP6, TP7, TP8, TP9, TP10, TP11, TP12, TP13: TEST_POINT; TP-1MMX1MM
U8: TPS65988
U9: W25X05CLSNIG

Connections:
ADCIN1: R4.1, R5.2, U8.6 (ADCIN1)
ADCIN2: R7.1, R10.2, U8.10 (ADCIN2)
ANT_SELECT: TP12.0, U8.49 (GPIO17(PEXT2))
AUDIO_EN: TP11.0, U8.48 (GPIO16(PEXT1))
DRAIN1: U8.8 (DRAIN1), U8.15 (DRAIN1_1), U8.19 (DRAIN1_2), U8.58 (DRAIN1_3)
DRAIN2: U8.7 (DRAIN2), U8.52 (DRAIN2_1), U8.56 (DRAIN2_2), U8.57 (DRAIN2_3)
FAULT1: U8.22 (I2C3_SDA(GPIO6)); also elsewhere on the board
FAULT2: U8.23 (I2C3_IRQ(GPIO7)); also elsewhere on the board
GND: C5.1, C8.1, C9.1, C11.1, C12.1, C13.1, C14.1, C15.2, C16.2, C43.1, C44.1, C45.1, C46.1, C53.1, C54.1, R5.1, R10.1, R23.1, R24.1, U8.20 (GND), U8.51 (GND1), U8.59 (GND2), U9.4 (GND); also elsewhere on the board
HRESET: C54.2, R24.2, U8.44 (HRESET); also elsewhere on the board
I2C1_IRQZ: R34.1, U8.29 (I2C1_IRQ); also elsewhere on the board
I2C1_SCL: U8.27 (I2C1_SCL); also elsewhere on the board
I2C1_SDA: U8.28 (I2C1_SDA); also elsewhere on the board
I2C2_IRQZ: U8.34 (I2C2_IRQ)
I2C2_SCL: R11.1, U8.32 (I2C2_SCL)
I2C2_SDA: R13.1, U8.33 (I2C2_SDA)
LDO_1V8: C8.2, U8.35 (LDO_1V8)
LDO_3V3: C5.2, C53.2, R4.2, R7.2, R11.2, R13.2, R30.2, R31.2, R32.2, R33.2, R34.2, U8.9 (LDO_3V3), U9.8 (VCC); also elsewhere on the board
unnamed: R23.2, TP2.0, U8.17 (GPIO1)
unnamed: R30.1, U9.3 (/WP)
unnamed: R33.1, U9.7 (/HOLD)
PD0-CC1: C46.2, U8.24 (C1_CC1); also elsewhere on the board
PD0-CC2: C45.2, U8.26 (C1_CC2); also elsewhere on the board
PD1-CC1: C44.2, U8.45 (C2_CC1); also elsewhere on the board
PD1-CC2: C43.2, U8.47 (C2_CC2); also elsewhere on the board
PORT0-D+: U8.50 (C1_USB_P(GPIO18)); also elsewhere on the board
PORT0-D-: U8.53 (C1_USB_N(GPIO19)); also elsewhere on the board
PORT0_VBUS: C15.1, U8.13 (VBUS1), U8.14 (VBUS1_1); also elsewhere on the board
PORT1-D+: U8.54 (C2_USB_P(GPIO20)); also elsewhere on the board
PORT1-D-: U8.55 (C2_USB_N(GPIO21)); also elsewhere on the board
PORT1_VBUS: C16.1, U8.3 (VBUS2_1), U8.4 (VBUS2); also elsewhere on the board
SPI_CLK: U8.38 (SPI_CLK(GPIO10)), U9.6 (CLK)
SPI_CS: R32.1, U8.39 (SPI_SS(GPIO11)), U9.1 (/CS)
SPI_MISO: R31.1, U8.36 (SPI_MISO(GPIO8)), U9.2 (DO(IO1))
SPI_MOSI: U8.37 (SPI_MOSI(GPIO9)), U9.5 (DI(IO0))
USB_SWITCH_OC: TP7.0, U8.21 (I2C3_SCL(GPIO5))
VCC3V3: C12.2, U8.5 (VIN_3V3); also elsewhere on the board
VCC5V: C9.2, C11.2, U8.25 (PP1_CABLE), U8.46 (PP2_CABLE); also elsewhere on the board
VCC_IN: C13.2, C14.2, U8.1 (PP_HV2_1), U8.2 (PP_HV2), U8.11 (PP_HV1_1), U8.12 (PP_HV1); also elsewhere on the board
XIO-P1: TP4.0, U8.18 (GPIO2)
XIO-P2: TP5.0, U8.30 (HPD1(GPIO3))
XIO-P3: TP6.0, U8.31 (HPD2(GPIO4))
XIO-P4: TP13.0, U8.40 (GPIO12)
XIO-P5: TP8.0, U8.41 (GPIO13)
XIO-P6: TP9.0, U8.42 (GPIO14(PWM))
XIO-P7: TP10.0, U8.43 (GPIO15(PWM))

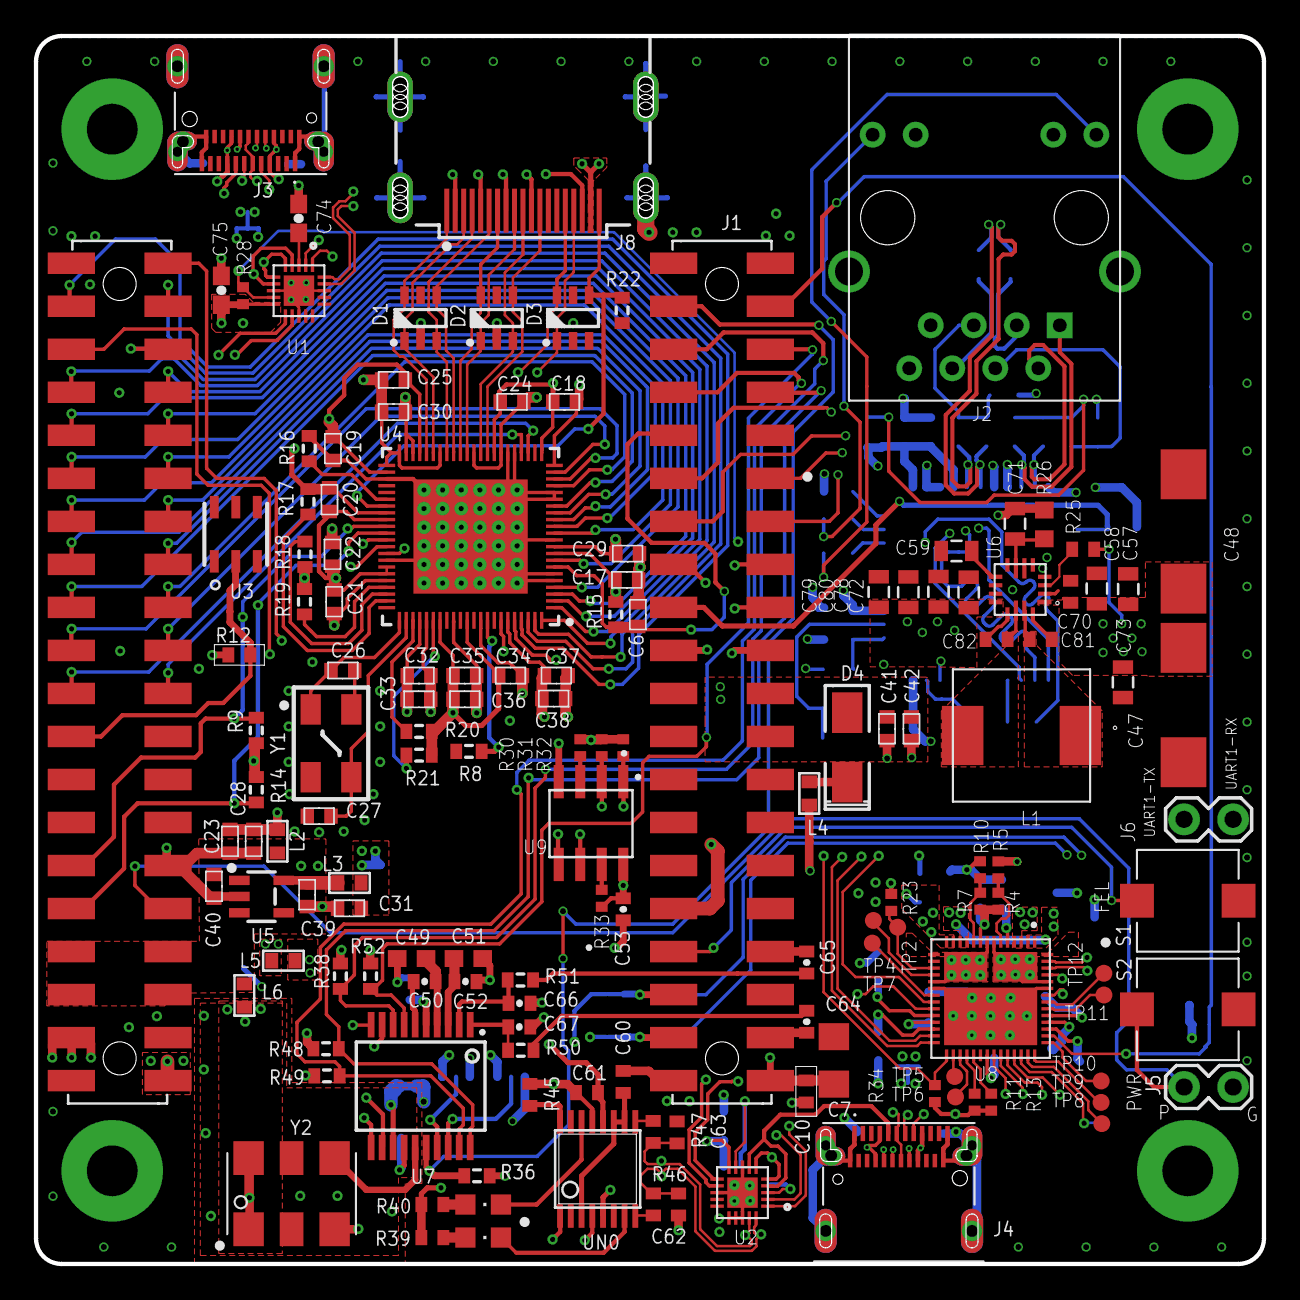
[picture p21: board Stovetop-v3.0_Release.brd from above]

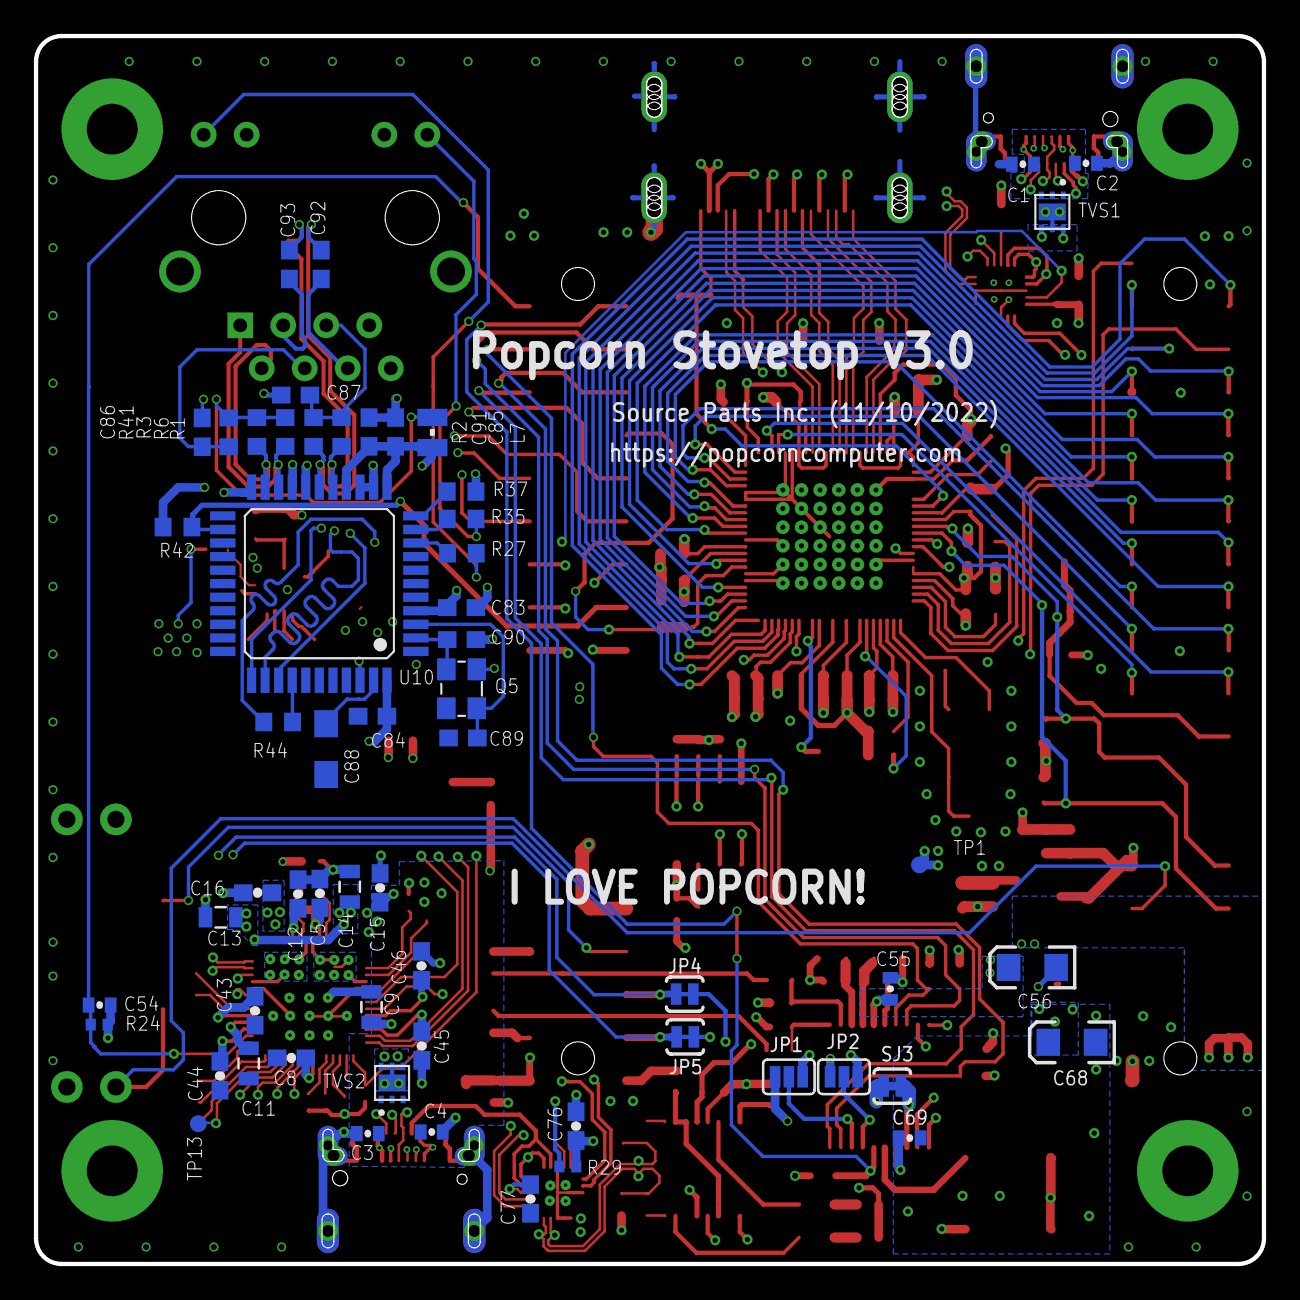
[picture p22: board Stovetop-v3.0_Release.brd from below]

Board: 6 copper layers, 72.5 x 72.5 mm, 200 parts (59 on the bottom side), 171 nets.

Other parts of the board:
DRILEGEND: DRILEGEND

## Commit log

2021-11-09 add v1.0
    [Stovetop-v1-Feedback.xlsx, Stovetop-v1.1.brd, Stovetop-v1.1.sch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]
2022-10-21 add v3.0
    [Stovetop-v3.0_Fab.gbr, Stovetop-v3.0_L1Top.gbr, Stovetop-v3.0_L2_Gnd.gbr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]

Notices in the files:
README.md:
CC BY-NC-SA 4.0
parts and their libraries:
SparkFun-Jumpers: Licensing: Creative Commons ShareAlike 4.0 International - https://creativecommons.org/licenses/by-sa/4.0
